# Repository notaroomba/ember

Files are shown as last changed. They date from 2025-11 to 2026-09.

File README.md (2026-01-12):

<h1 align="center">
  <br>
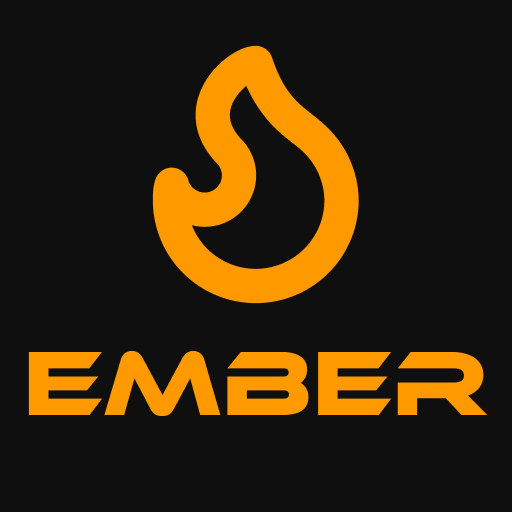
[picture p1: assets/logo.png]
  
  <br>
  Ember
  <br>
</h1>

<h4 align="center">
A high-performance USB-C powered reflow hotplate with Bluetooth connectivity and intelligent temperature control!
</h4>

<div align="center">





</div>

<p align="center">
  <a href="#key-features">Key Features</a> •
  <a href="#pcb">PCB</a> •
  <a href="#case">Case</a> •
  <a href="#heatbed">Heatbed</a> •
  <a href="#credits">Credits</a> •
  <a href="#license">License</a>
</p>

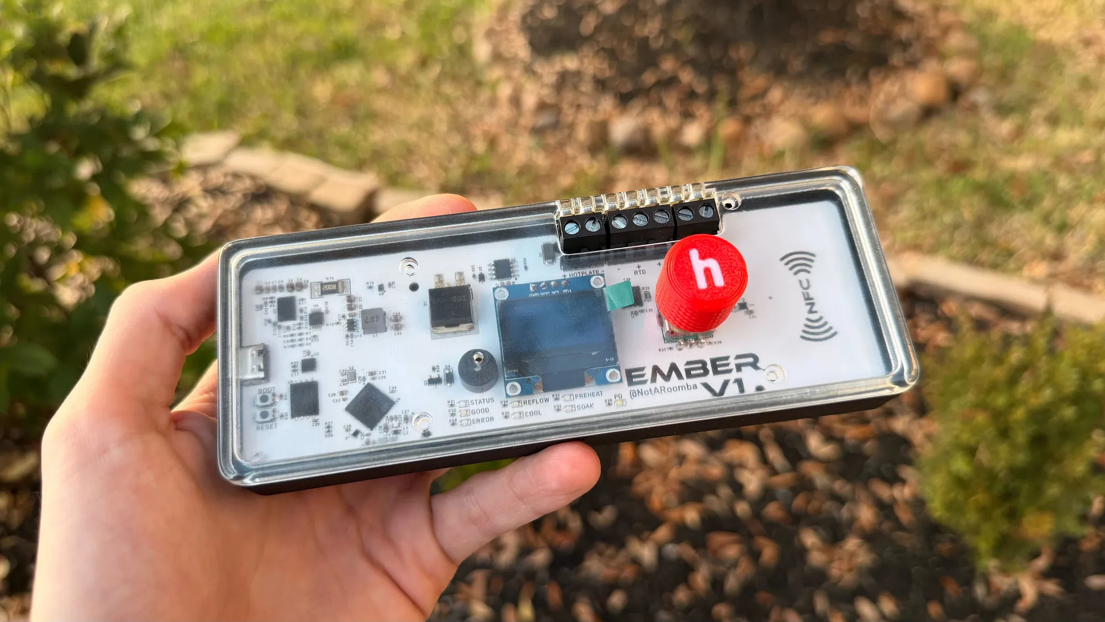
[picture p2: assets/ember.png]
Ember


<!-- <img src="blender/render.png" alt="Ember Render" width="800"/> -->

## Key Features

- **USB-C Power Delivery** up to 100W (20V) using TI's TPS25730D
- **STM32WB55CG** microcontroller with Bluetooth support
- **Large ~~400mm x 400mm~~ ~~200mm x 200mm~~ 120mm x 120mm (for now) flexible heatbed** for big PCB reflow
- **Dual temperature sensing** with MAX6675 thermocouple and PT1000 RTD
- **OLED display** with rotary encoder for easy control and preset management
- **NFC support** for wireless temperature profile transfer and preset storage
- **Gate driver** for precise PWM heatbed control
- **Current and board temperature monitoring** for safety
- **32MB Flash memory** for graphics and data storage
- **Portable design** with custom acrylic / nylon case

## PCB

Designed in KiCad!

### Schematic

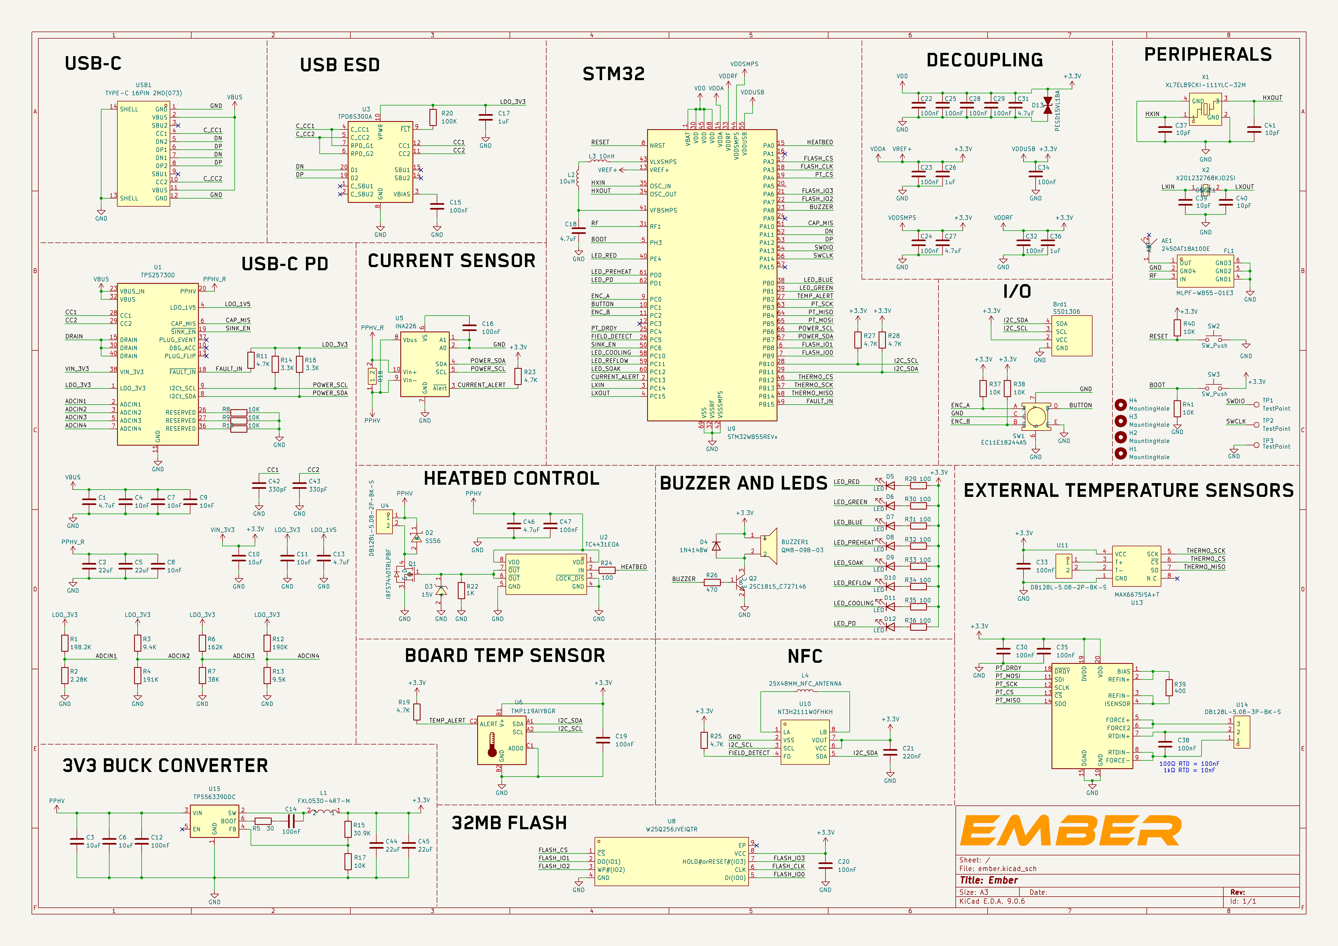
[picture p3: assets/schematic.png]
Schematic


### PCB Layout

**Front:**
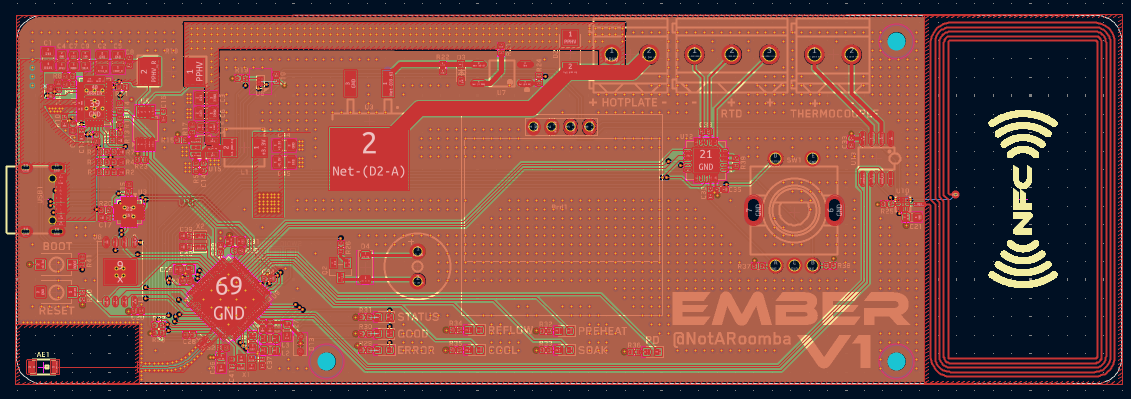
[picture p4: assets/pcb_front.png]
PCB Front


**Back:**
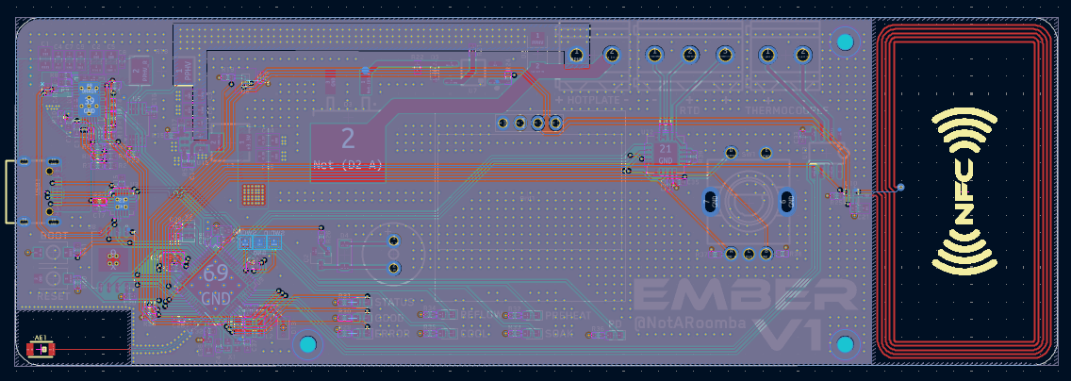
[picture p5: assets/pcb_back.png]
PCB Back


**Ground Plane:**
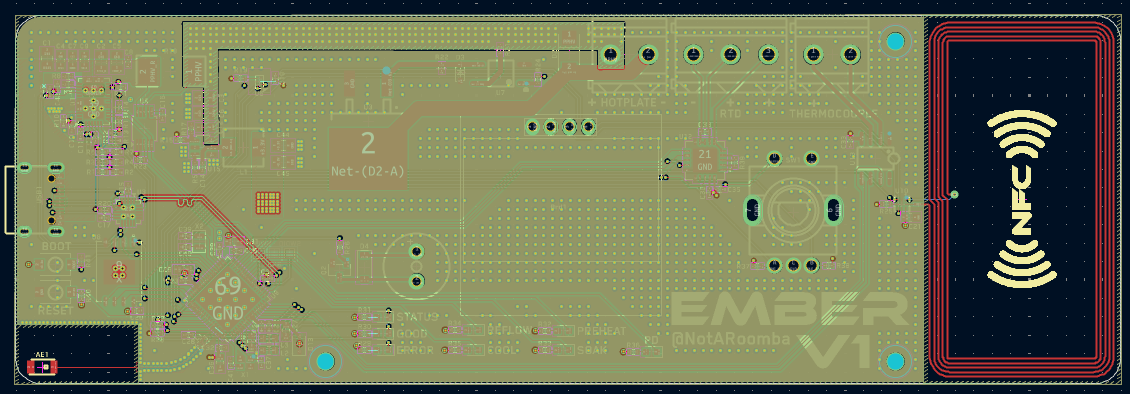
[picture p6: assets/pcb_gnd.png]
PCB Ground


**Power Plane:**
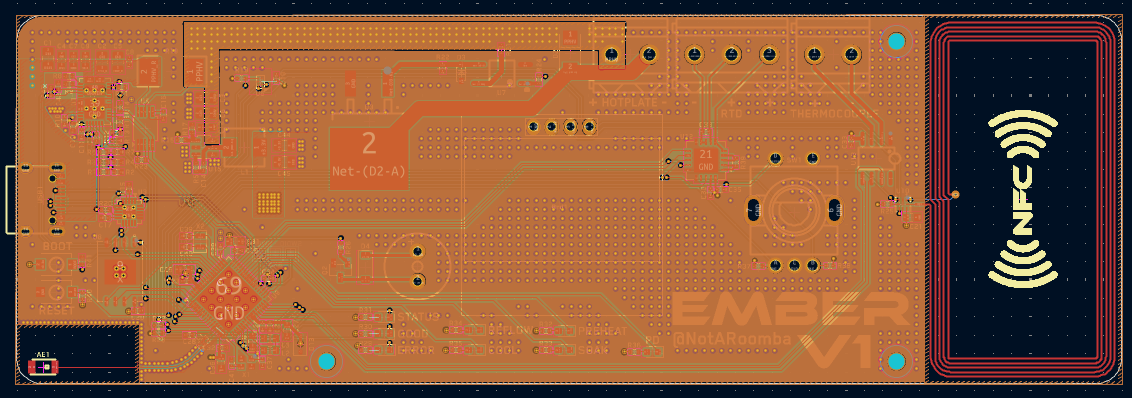
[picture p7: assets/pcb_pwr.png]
PCB Power


Board dimensions: 50mm x 150mm

## Case

Custom designed case in OnShape with practical features:

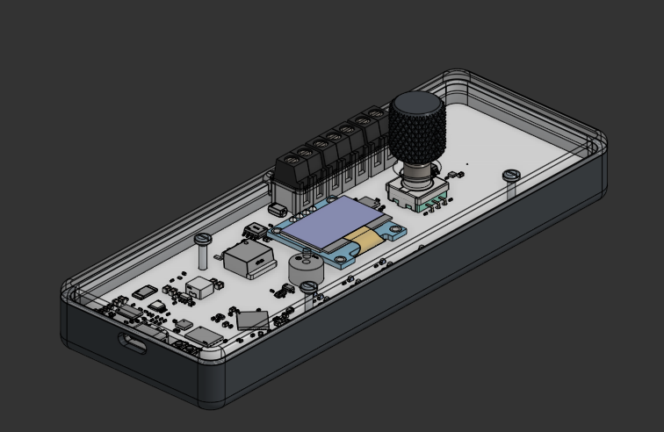
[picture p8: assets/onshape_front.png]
Case Front View

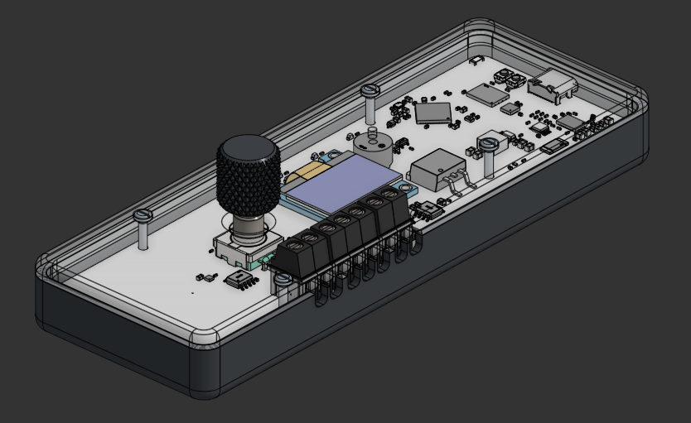
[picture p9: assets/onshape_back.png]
Case Back View


Features:
- **USB-C port cutout** with flush cable routing
- **Screw terminal access** for heatbed and temperature sensor connections
- **Heatset inserts** for secure assembly with slotted cylindrical head screws
- **High-quality materials**: PA11-HP Nylon base with acrylic top for visibility
- **Rounded corners** for aesthetics and safety

## Heatbed

The heatbed uses JLCPCB's flexible heater technology for cost-effective large-area heating.

The flexible heater connects to the main PCB via screw terminals!

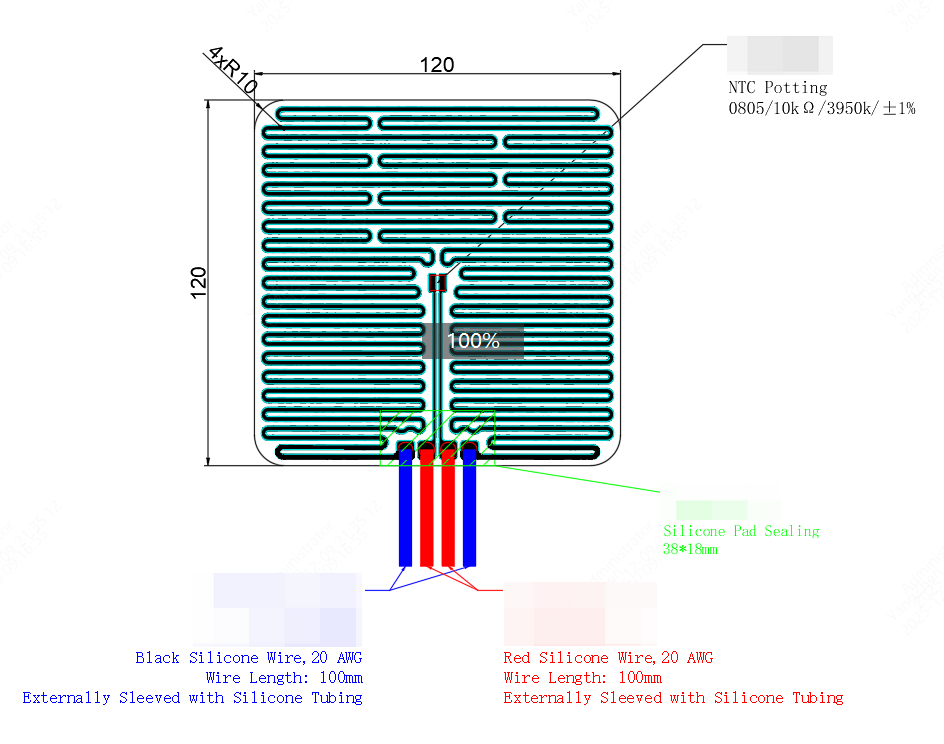
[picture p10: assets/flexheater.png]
Heatbed


## 3D Renders

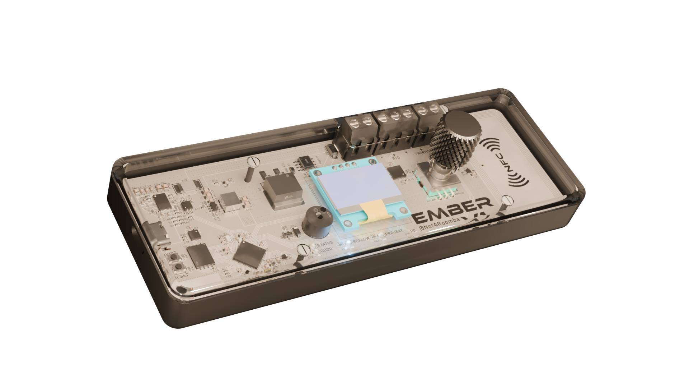
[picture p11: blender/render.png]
Render 1

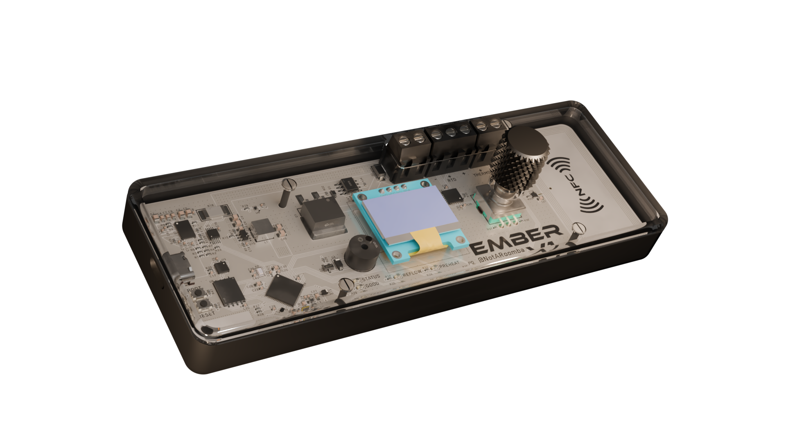
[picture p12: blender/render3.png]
Render 2

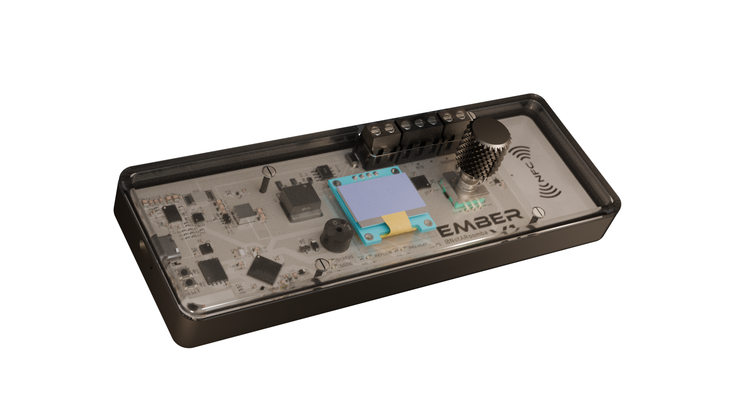
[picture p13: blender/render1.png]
Render 1

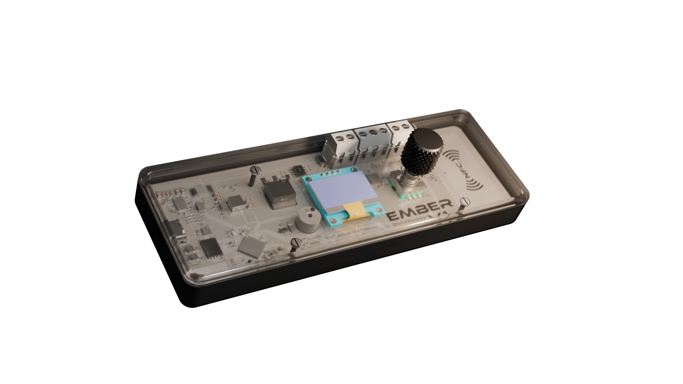
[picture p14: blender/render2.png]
Render 2


## Credits

This project uses:

- [KiCad](https://www.kicad.org/)
- [OnShape](https://www.onshape.com/) for case design
- [Blender](https://www.blender.org/) for 3D renders
- [STM32CubeMX](https://www.st.com/en/development-tools/stm32cubemx.html)
- Inspiration from [this reflow hotplate project](https://github.com/ikajdan/reflow-hot-plate)
- [Arduino GFX Tool](https://arduinogfxtool.netlify.app/) for OLED UI/UX design

## You may also like...

- [Cyberboard](https://github.com/NotARoomba/Cyberboard) – A Raspberry Pi Pico-sized STM32 development board with Bluetooth
- [Trace](https://github.com/NotARoomba/Trace) – A comprehensive PCB ruler with reference footprints
- [CyberCard](https://github.com/NotARoomba/CyberCard) – A Cyberpunk themed NFC hacker card
- [Niveles De Niveles](https://github.com/NotARoomba/NivelesDeNiveles) – Real-time flood alert app
- [Linea](https://github.com/NotARoomba/Linea) – An EMR tablet
- [Tamaki](https://github.com/NotARoomba/Tamaki) – A cute HackPad

## License

MIT

---

> [notaroomba.dev](https://notaroomba.dev) &nbsp;&middot;&nbsp;
> GitHub [@NotARoomba](https://github.com/NotARoomba) &nbsp;&middot;&nbsp;

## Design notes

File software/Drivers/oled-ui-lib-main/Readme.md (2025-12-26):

# Arduino Oled UI Components 
A component-based UI library for SSD1306 oled screens, tested on 128x64 version.

## Prerequisites
- **Adafruit SSD1306 Library**: Install via Arduino Library Manager.

## Usage
Include relevant headrs in your sketch.
```cpp
#include <Adafruit_GFX.h>
#include <Adafruit_SSD1306.h>

#include "UIRenderer.h"
#include "UILabel.h"
#include "UIButton.h"
// Include other components as needed
```

### Basic Example
This example displayes a label and a button. See examples/ folder for further usage examples.
```cpp
#include <SPI.h>
#include <Wire.h>
#include <Adafruit_GFX.h>
#include <Adafruit_SSD1306.h>

#include "UIRenderer.h"
#include "UILabel.h"
#include "UIButton.h"

#define SCREEN_WIDTH 128
#define SCREEN_HEIGHT 64
#define OLED_RESET    -1

Adafruit_SSD1306 display(SCREEN_WIDTH, SCREEN_HEIGHT, &Wire, OLED_RESET);

// Instantiate the UI renderer
UIRenderer ui(display);

// Global variables
UILabel* helloLabel;
UIButton* clickButton;

void onButtonClick() {
  Serial.println("Button clicked!");
}

void setup() {
  Serial.begin(115200);

  if (!display.begin(SSD1306_SWITCHCAPVCC, 0x3C)) {
    Serial.println(F("SSD1306 allocation failed"));
    for (;;);
  }

  // Create UI components
  helloLabel = new UILabel("Hello, World!", 0, 0, 2);
  clickButton = new UIButton("Click Me", 0, 30, 80, 16, WHITE, BLACK, onButtonClick);

  // Add components to UI renderer
  ui.addComponent(helloLabel);
  ui.addComponent(clickButton);

  // Initial render
  ui.render();
}

void loop() {
  // Simulate button press (for demonstration purposes)
  delay(2000);
  onButtonClick();
}
```

### Components Reference

#### UILabel

Displays text on the screen.

**Usage Example**:

```
UILabel* myLabel = new UILabel("Sample Text", x, y, textSize, textColor);
ui.addComponent(myLabel);
```

- **Parameters**:
  - `text`: The text to display.
  - `x`, `y`: Position on the screen.
  - `textSize`: Size of the text (default is `1`).
  - `textColor`: Color of the text (default is `WHITE`).

#### UIButton

A clickable button with a label.

**Usage Example**:

```
void onButtonClick() {
  // Handle button click
}

UIButton* myButton = new UIButton("Press", x, y, width, height, bgColor, textColor, onButtonClick);
ui.addComponent(myButton);
```

- **Parameters**:
  - `label`: Button label text.
  - `x`, `y`: Position on the screen.
  - `width`, `height`: Size of the button.
  - `bgColor`: Background color (default is `WHITE`).
  - `textColor`: Text color (default is `BLACK`).
  - `onClick`: Callback function when the button is clicked.

#### UISeparator

Draws a horizontal line to separate UI sections.

**Usage Example**:

```
UISeparator* separator = new UISeparator(x, y, width, color);
ui.addComponent(separator);
```

- **Parameters**:
  - `x`, `y`: Starting position.
  - `width`: Length of the separator.
  - `color`: Line color (default is `WHITE`).

#### UISpinner

An animated spinner to indicate processing.

**Usage Example**:

```
UISpinner* spinner = new UISpinner(centerX, centerY, radius, color);
ui.addComponent(spinner);
```

- **Parameters**:
  - `centerX`, `centerY`: Center position.
  - `radius`: Size of the spinner.
  - `color`: Spinner color (default is `WHITE`).

**Note**: Call `spinner->update()` in the loop to animate.

#### UINavbar

A navigation bar with menu items.

**Usage Example**:

```
void onHomeSelected() {
  // Handle home selection
}

UINavbar* navbar = new UINavbar(x, y, width, height);
navbar->addItem(new UINavbarItem("Home", onHomeSelected));
ui.addComponent(navbar);
```

- **Parameters**:
  - `x`, `y`: Position on the screen.
  - `width`, `height`: Size of the navbar.
  - `bgColor`, `textColor`, `selectedColor`: Colors for various states.

#### UIProgressBar

Displays progress for operations.

**Usage Example**:

```
UIProgressBar* progressBar = new UIProgressBar(x, y, width, height);
progressBar->setProgress(50); // Set progress to 50%
ui.addComponent(progressBar);
```

- **Parameters**:
  - `x`, `y`: Position on the screen.
  - `width`, `height`: Size of the progress bar.
  - `bgColor`, `barColor`: Colors for background and progress.

#### UIRadioButton

Allows selection from multiple options.

**Usage Example**:

```
void onRadioSelection(uint8_t index) {
  // Handle selection
}

UIRadioButton* radioGroup = new UIRadioButton(x, y, textSize, textColor, onRadioSelection);
radioGroup->addOption(new UIRadioOption("Option 1"));
radioGroup->addOption(new UIRadioOption("Option 2"));
ui.addComponent(radioGroup);
```

- **Parameters**:
  - `x`, `y`: Position on the screen.
  - `textSize`: Text size (default is `1`).
  - `textColor`: Text color (default is `WHITE`).
  - `onSelectionChange`: Callback function when the selection changes.

#### UIToggleSwitch

A binary on/off switch.

**Usage Example**:

```
void onToggle(bool state) {
  // Handle toggle
}

UIToggleSwitch* toggleSwitch = new UIToggleSwitch(x, y, width, height, initialState, onColor, offColor, onToggle);
ui.addComponent(toggleSwitch);
```

- **Parameters**:
  - `x`, `y`: Position on the screen.
  - `width`, `height`: Size of the switch.
  - `initialState`: Starting state (`true` for on, `false` for off).
  - `onColor`, `offColor`: Colors for the on and off states.
  - `onToggle`: Callback function when the state changes.

#### UINumericInput

Adjust numerical values.

**Usage Example**:

```
void onValueChange(int32_t newValue) {
  // Handle value change
}

UINumericInput* numericInput = new UINumericInput(x, y, minValue, maxValue, initialValue, textSize, textColor, onValueChange);
ui.addComponent(numericInput);
```

- **Parameters**:
  - `x`, `y`: Position on the screen.
  - `minValue`, `maxValue`: Minimum and maximum values.
  - `initialValue`: Starting value.
  - `textSize`: Text size (default is `1`).
  - `textColor`: Text color (default is `WHITE`).
  - `onValueChange`: Callback function when the value changes.

#### UIMessageBox

Displays messages or alerts.

**Usage Example**:

```
UIMessageBox* messageBox = new UIMessageBox("Alert!", x, y, width, height);
messageBox->show(); // To display
messageBox->hide(); // To hide
ui.addComponent(messageBox);
```

- **Parameters**:
  - `message`: The message to display.
  - `x`, `y`: Position on the screen.
  - `width`, `height`: Size of the message box.
  - `bgColor`, `textColor`, `borderColor`: Colors for background, text, and border.

#### UILineChart

Visualizes data trends.

**Usage Example**:

```
UILineChart* lineChart = new UILineChart(x, y, width, height);
lineChart->addDataPoint(sensorValue);
ui.addComponent(lineChart);
```

- **Parameters**:
  - `x`, `y`: Position on the screen.
  - `width`, `height`: Size of the chart.
  - `lineColor`: Color of the line (default is `WHITE`).

#### UIDropdownMenu

Selects from a list of options.

**Usage Example**:

```
void onDropdownSelect(uint8_t index) {
  // Handle selection
}

UIDropdownMenu* dropdownMenu = new UIDropdownMenu(x, y, width, height, bgColor, textColor, selectedColor, onDropdownSelect);
dropdownMenu->addItem("Option A");
dropdownMenu->addItem("Option B");
ui.addComponent(dropdownMenu);
```

- **Parameters**:
  - `x`, `y`: Position on the screen.
  - `width`, `height`: Size of the dropdown menu.
  - `bgColor`, `textColor`, `selectedColor`: Colors for background, text, and selected item.
  - `onItemSelect`: Callback function when an item is selected.

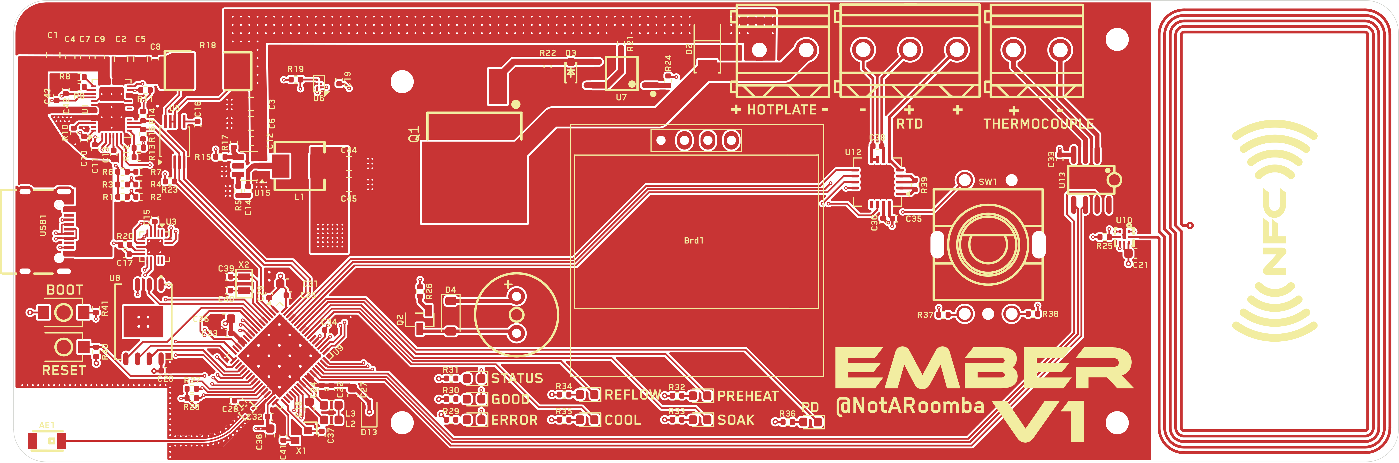
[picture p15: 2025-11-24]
assets/ember-F_Cu.png

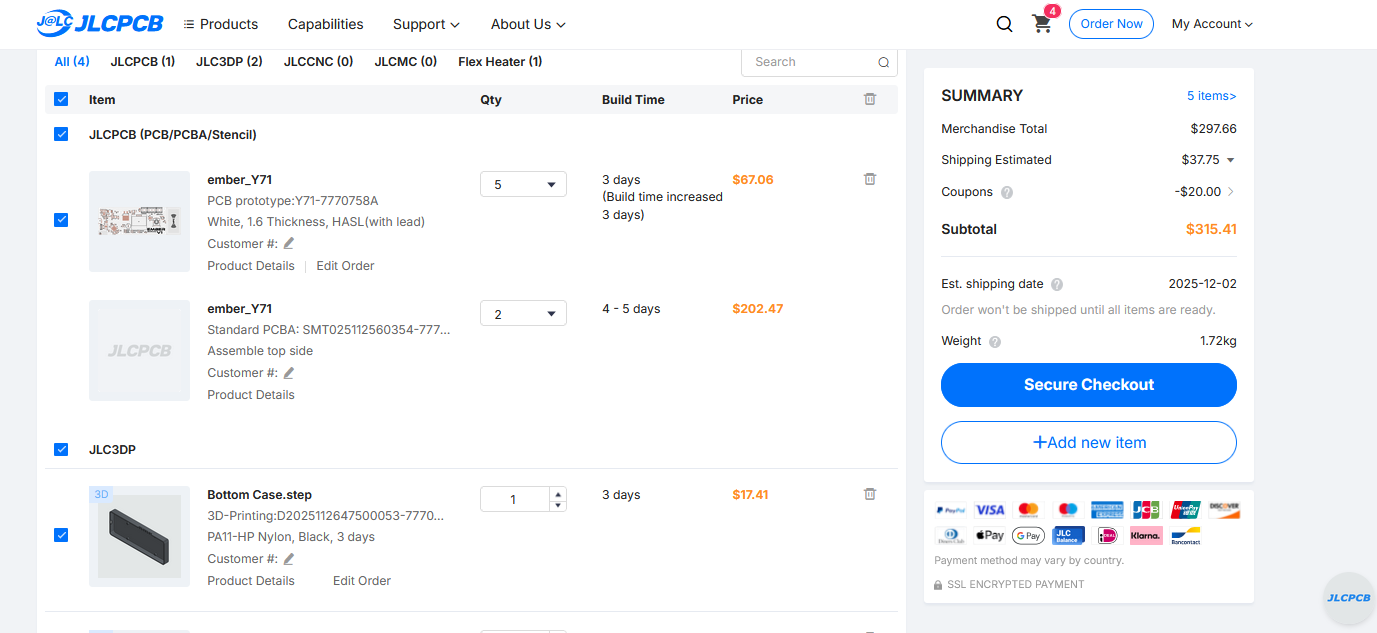
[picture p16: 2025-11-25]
assets/jlc_1.png

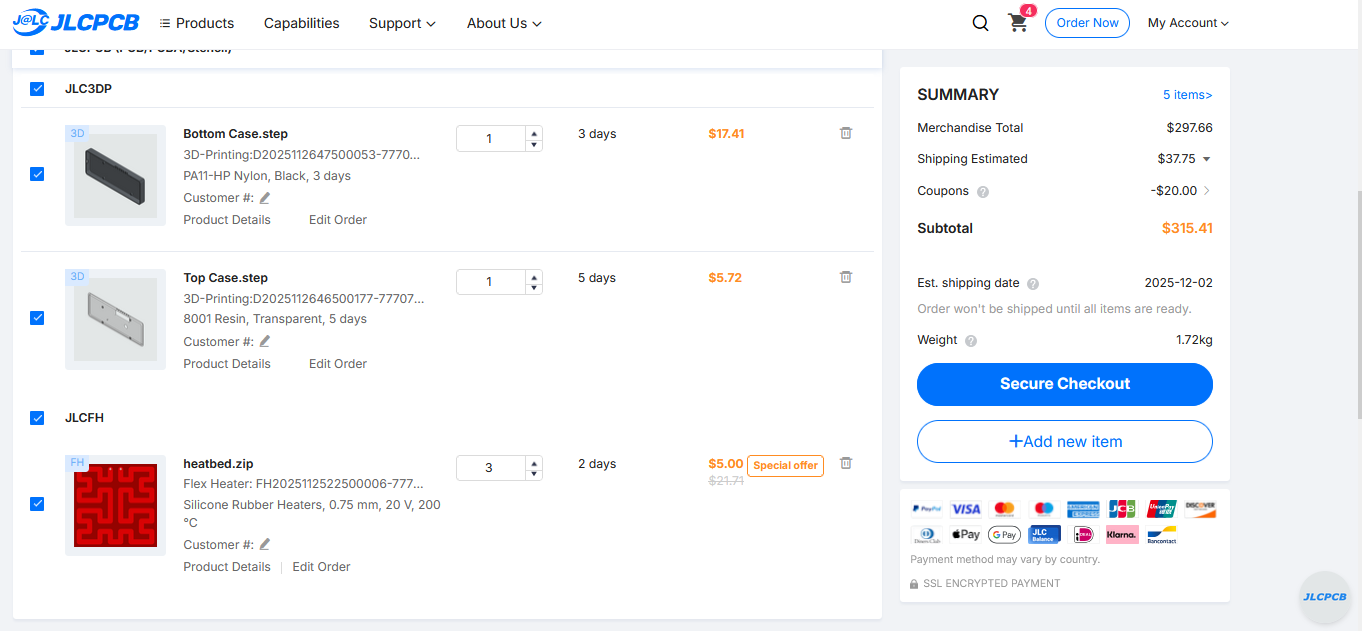
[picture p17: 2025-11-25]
assets/jlc_2.png

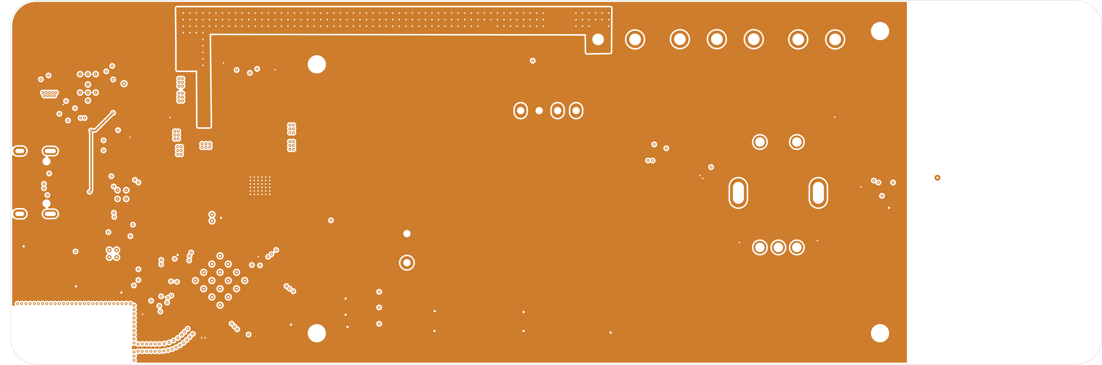
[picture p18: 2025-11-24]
assets/ember-In2_Cu.png

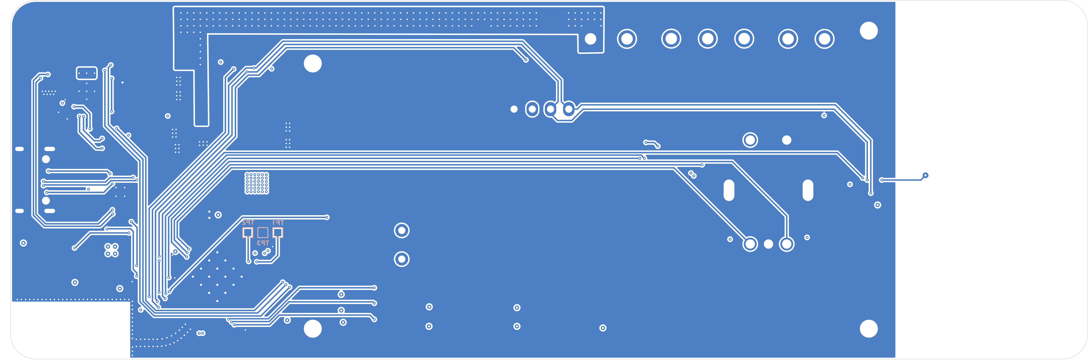
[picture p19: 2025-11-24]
assets/ember-B_Cu.png

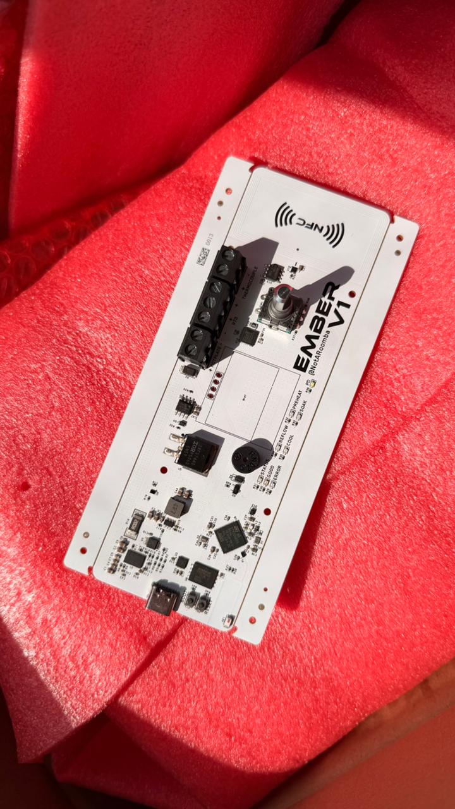
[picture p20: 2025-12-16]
assets/ember_pcb.jpeg

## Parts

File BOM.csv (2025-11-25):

Item | Price | Source | Alt Source
PT1000 | 4.28 | https://es.aliexpress.com/item/1005010267999683.html
Thermocouple | 2.66 | https://es.aliexpress.com/item/4000097994613.html
OLED | 2.24 | https://es.aliexpress.com/item/1005006152880748.html
Heatset Inserts | 3.70 | https://es.aliexpress.com/item/1005006838108683.html
Potentiometer Knob | 1.25 | https://es.aliexpress.com/item/1005009085015664.html
EC11 | 3.30 | https://es.aliexpress.com/item/1005007703545657.html
Black Nylon M2 Screws | 0.88 | https://es.aliexpress.com/item/1005004359782700.html
PCB | 269.53 | JLCPCB
Top Case (Clear) | 5.72 | JLC3DP
Bottom Case (High temp filament) | 17.41 | JLC3DP
Heatbed | 5.00 | JLCFH
Shipping (JLC) (DDP) | 37.75 | JLC
Shipping (AliExpress) | 8.11 | AliExpress
JLC Coupon | -20.00 | JLC
Total | 341.83

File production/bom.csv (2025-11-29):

Designator | Footprint | Quantity | Value | LCSC Part #
AE1 | ANT-SMD_L3.2-W1.6 | 1 | 2450AT18A100E | C89334
BRD1 | 128x64OLED | 1 | SSD1306
BUZZER1 | BUZ-TH_BD9.0-P4.00-D0.6-FD | 1 | QMB-09B-03 | C96256
C1 | 0805 | 1 | 4.7uF
C10, C11 | 0402 | 2 | 10uF
C12, C47 | 0603 | 2 | 100nF
C13 | 0402 | 1 | 4.7uF
C14, C15, C16, C19, C20, C22, C23, C24, C25, C28, C29, C30, C32, C33, C34, C35, C38 | 0402 | 17 | 100nF
C17 | 0402 | 1 | 1uF
C18, C27, C31, C46 | 0603 | 4 | 4.7uF
C2, C44, C45, C5 | 0805 | 4 | 22uF
C21 | 0603 | 1 | 220nF | C21120
C26, C36 | 0603 | 2 | 1uF
C3, C6 | 0805 | 2 | 10uF
C37, C39, C40, C41 | 0402 | 4 | 10pF
C4, C7, C9 | 0603 | 3 | 10nF
C42, C43 | 0402 | 2 | 330pF
C8 | 0402 | 1 | 10nF
D10, D11, D8, D9 | 0603 | 4 | LED | C965800
D12 | 0603 | 1 | LED | C2290
D13 | D_SOD-323 | 1 | PESD15VL1BA
D2 | SMA_L4.3-W2.6-LS5.2-RD | 1 | SS56 | C65009
D3 | SOD-323_L1.7-W1.3-LS2.6-RD | 1 | 15V | C19077448
D4 | D_SOD-123 | 1 | 1N4148W
D5 | 0603 | 1 | LED | C965799
D6 | 0603 | 1 | LED | C19171301
D7 | 0603 | 1 | LED | C965807
FL1 | FILTER-SMD_6P-L1.6-W1.0-P0.50-BL | 1 | MLPF-WB55-01E3 | C2651048
L1 | IND-SMD_L5.4-W5.2_FXL0530 | 1 | FXL0530-4R7-M | C177246
L2 | 0603 | 1 | 10uH
L3 | 0603 | 1 | 10nH
L4 | 25X48MM_NFC_ANTENNA | 1 | 25X48MM_NFC_ANTENNA
Q1 | TO-263-2_L10.0-W9.1-P5.08-LS15.2-BR | 1 | IRFS7440TRLPBF | C409762
Q2 | SOT-23-3_L2.9-W1.3-P1.90-LS2.4-BR | 1 | 2SC1815_C727146 | C727146
R1 | 0402 | 1 | 198.2K | C3013157
R10, R17, R37, R38, R40, R41, R8, R9 | 0402 | 8 | 10K
R11, R19, R23, R25, R27, R28 | 0402 | 6 | 4.7K
R12 | 0402 | 1 | 190K | C2998070
R13 | 0402 | 1 | 9.5K | C96273
R14, R16 | 0402 | 2 | 3.3K
R15 | 0402 | 1 | 30.9K
R18 | RES-SMD_L6.4-W3.2-1 | 1 | HOLLR2512-3W-2MR-1% | C2994640
R2 | 0402 | 1 | 2.28K | C2998174
R20 | 0402 | 1 | 100K
R22 | 0402 | 1 | 1K
R24, R29, R30, R31, R32, R33, R34, R35, R36 | 0402 | 9 | 100
R26 | 0402 | 1 | 470
R3 | 0402 | 1 | 9.4K | C852970
R39 | 0805 | 1 | 400 | C153298
R4 | 0402 | 1 | 191K | C2998070
R5 | 0402 | 1 | 30
R6 | 0402 | 1 | 162K
R7 | 0402 | 1 | 38K | C852750
SW1 | SW-TH_EC11E18244A5 | 1 | EC11E18244A5 | C255515
SW2, SW3 | SW-SMD_L3.9-W3.0-P4.45 | 2 | SW_Push | C720477
TP1, TP2, TP3 | TestPoint_Pad_1.0x1.0mm | 3 | TestPoint
U1 | Texas_REF0038A_WQFN-38-2EP_6x4mm_P0.4 | 1 | TPS25730D
U10 | XQFN-8_L1.6-W1.6-P0.50-BL_NT3H2111W0FHKH | 1 | NT3H2111W0FHKH | C710403
U11, U4 | CONN-TH_2P-P5.08_DB128L-5.08-2P-BK-S | 2 | DB128L-5.08-2P-BK-S | C430601
U12 | TQFN-20-1EP_5x5mm_P0.65mm_EP3.25x3.25mm | 1 | MAX31865xTP
U13 | SOIC-8_L5.0-W4.0-P1.27-LS6.0-BL | 1 | MAX6675ISA+T | C16030
U14 | CONN-TH_3P-P5.08_DB128L-5.08-3P-BK-S | 1 | DB128L-5.08-3P-BK-S | C430602
U15 | SOT-23-6 | 1 | TPS56339DDC
U2 | SOIC-8_L4.9-W3.9-P1.27-LS6.0-BL | 1 | TC4431EOA | C2909520
U3 | WQFN-20-1EP_3x3mm_P0.4mm_EP1.7x1.7mm_ThermalVias | 1 | TPD6S300A
U5 | VSSOP-10_3x3mm_P0.5mm | 1 | INA226
U6 | Texas_DSBGA-6_0.95x1.488mm_Layout2x3_P0.4mm | 1 | TMP119AIYBGR
U8 | WSON-8_L8.0-W6.10-P1.27-BL-EP | 1 | W25Q256JVEIQTR | C97522
U9 | QFN-68-1EP_8x8mm_P0.4mm_EP6.4x6.4mm | 1 | STM32WB55REVx
USB1 | USB-C-SMD_TYPE-C-6PIN-2MD-073 | 1 | TYPE-C 16PIN 2MD(073) | C2765186
X1 | CRYSTAL-SMD_4P-L2.0-W1.6-BL | 1 | XL7EL89CKI-111YLC-32M | C2965582
X2 | OSC-SMD_L2.0-W1.2 | 1 | X201232768KJD2SI | C383843

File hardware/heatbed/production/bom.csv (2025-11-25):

Designator | Footprint | Quantity | Value | LCSC Part #
R1, R2 | 0805 | 2 | R

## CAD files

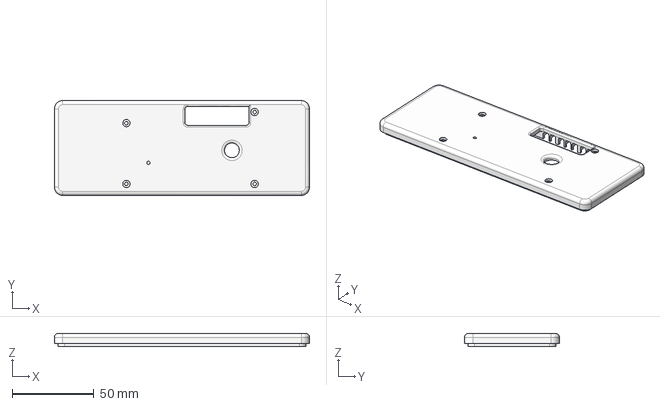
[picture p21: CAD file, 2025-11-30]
hardware/case/Top Case.step
156.0 x 58.0 x 8.00 mm

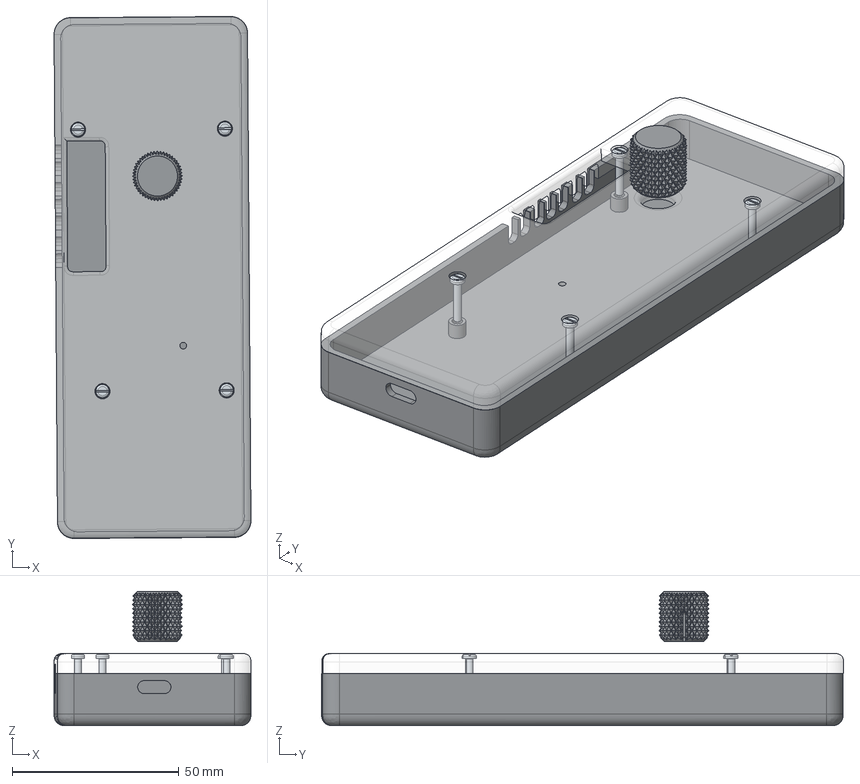
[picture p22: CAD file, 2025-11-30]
hardware/case/Ember_NO_PCB.step
59.0 x 156.4 x 40.3 mm
Slotted pan head screw M2x0.40 x 12 x 4
EC11 Knob
Bottom Case
Top Case

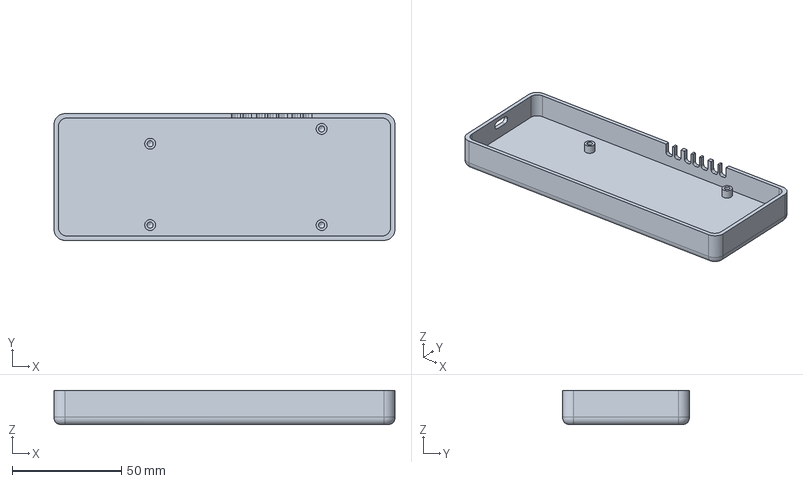
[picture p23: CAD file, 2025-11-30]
production/Bottom Case.step
156.0 x 58.0 x 15.6 mm

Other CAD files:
hardware/board/ember/ember/ember.ipt

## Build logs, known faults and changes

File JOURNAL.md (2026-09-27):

<!--
  Exported from Hack Club Blueprint on 2026-09-27.
  Source: https://blueprint.hackclub.com/projects/1701
-->

## 11/14/2025 - Research  

_Time spent: 3.0h_  

This is another project that surged out of nowhere (like trace) but mainly because I want to be able to solder/reflow my own PCB's in my house to be able to save cost and make bigger and better projects in the future (\*cough\* \*cough\* robotic arm \*cough\* \*cough\*). 

While I could buy a hotplate in the shop, I feel like it's too small and I might need to reflow bigger PCB's so just in case, I want to build a large custom hotplate that has these characteristics:

- Powered by USB-C
- Portable/Easy to store
- OLED screen + knob and button to config
- Cool looking case (opportunity to learn CAD before making a robotic arm/rocket)

Looking through the internet to see if anyone has done anything like this, I stumbled on this [repo](https://github.com/ikajdan/reflow-hot-plate/tree/main). While cool looking, it uses an external power supply and has a relatively small heatbed (80mm x 80mm). I'm aiming for 4 times that (in terms of area) with a 160mm x 160mm heatbed (or even bigger).

Doing more research and looking at materials, making a heatbed out of aluminum and one layer of copper costs a lot for big boards (slabs of aluminum)



Or even a bit smaller:



BUT, JLCPCB HAS THIS NEW COOL THING CALLED FLEX HEATERS THAT ARE WAYY CHEAPER AND CAN GO FOR BIGGER BC THEY'RE ALL AT 9 USD! SO being the capitalist that I am, I am going to capitalize on these savings and use one.



Now all that's left is to design the board. As I want USB-C PD, I am thinking about using a STM32G0B1KE (32 pin version) as it's powerful enough to do everything that I want it to do. I also would need a 3V3 converter (LM3281YFQR). In addition to a mosfet to control the how much current is going through (PWM). I also plan on adding a bunch of redundancy like USB-C ESD protection, fuses, current sensors, and temperature sensors (Thermocouple and Pt1000). 

Since this is going to be a flexible heater, I will also need a way to "prop" it up in the air so that it doesn't burn my desk. I plan on using an aluminum sheet with a hole in each corner to insert a "leg" (screw or smth) to be able to prop it up. Then at the bottom I plan on having a nice case (titanium /j) for the PCB and screw terminals to connect it to the hotplate/heatpad/flex heater.  

## 11/15/2025 - Start of Schematic  

_Time spent: 7.0h_  

I first created a new KiCad project and then opened up STM32CubeMX and followed this [guide](https://wiki.st.com/stm32mcu/wiki/STM32StepByStep:Getting_started_with_USB-Power_Delivery_Sink) on the ST website to configure USB PD. I also changed the processor to the STM32G0B1CBT6 as the other one didn't have a second CC pin due to the pin count.

Yknow what, scratch that, I'm a Texan and should be loyal to TI. So I'm gonna go with a TPS25730D and then use an STM32WB55 to get bluetooth support (everythings better with bluetooth lol). Jokes aside, I am going with TI because I want to complete this project in 3 days (crazy right?) and I feel more comfortable with their chips (Also serves as practice for when I have to work with Athena's PD chip).

For the mosfet I will be using IRFB3207 and TLP183 to drive it (taken from the original repo) and for temperature sensors, MAX6675 (thermocouple to digital), and a PT1000 with opamps to filter/amplify the signal. 

I will also be using LM22676MR-ADJ as a good step down converter from high voltages (42V just in case I want more power lol).



I added the components and started wiring up the ESD and USB-C port first:



After that I finished wiring up the USB-C PD chip. (Yes I made sure that there were pull up resistors on the I2C lines)



## 11/16/2025 - Worked on Schematic  

_Time spent: 8.0h_  

I started wiring up the STM32 and configuring it in STM32CubeMX. THIS TIME LOOKING AT THE REFERENCE SCHEMATIC AND NOT COPY PASTING TO AVOID [ERRORS](https://blueprint.hackclub.com/projects/491).





THIS TIME I ACTUALLY ADDED PULL UP RESISTORS ON THE I2C LINES AND DOUBLE CHECKED THE DECOUPLING CAPACITOR VALUES. 

I researched a bit about the different screens like the ones on the flipper zero but the standard I2C OLED is fine (SSD1306). I found this cool tool to create UI/UX so I'll put it here to save for later (https://arduinogfxtool.netlify.app/)

I also added in a bit more stuff like current sensor, buzzer, and board thermometer just in case. I might also add in NFC functionality to be able to wirelessly transfer temp data to the board/have presets set in NFC tags and I just put it on top and let it go (overkill but why half ass it).

I also added a 32MB flash to add images/graphcs onto the OLED (might be possible)

I hope to find this encoder somewhere: https://tech.alpsalpine.com/e/products/detail/EC11E18244A5/
 I also spent some time thinking about the case:


(very crude)

I'd want it made out of a high quality plastic (PA11-HP Nylon) or acrylic to be able to see the board interior with rounded corners and space to fit the board and OLED/Encoder. I might also include one of those push-push-switches to turn it on or off. (sends signal to STM32 to disable USB-C PD and turns off the display/lights. OR I COULD DO THE BACK AS (PA11-HP Nylon) AND THE TOP COVER AS ACRYLIC, but I'm too tired to think so tmrw I'll finish the schematic and start the routing.

## 11/17/2025 1 AM - STM32 Pinout and Most Peripherals  

_Time spent: 5.0h_  

I started by first defining the pinout for the STM32, as I wanted to use most of the pins, I added some status LED's and a buzzer. Continuing on from yesterday's work, I skimmed through the datasheets of each component to see which extra pins I would need to add them immediately and not have to worry about adding them later. I had some trouble with the timers and flash as I could only use 2 timers (out of 4) so I needed a way to get input from the rotary encoder, set the heatbed, and also to control the buzzer. After researching a bit more, I ended up using LPTIM1 for the rotary encoder as I say that It had input for that.

After configuring all of the pins, my STM32 looked like this:





After that I went to work wiring up the rest of the peripherals like the flash, buzzer, board temperature sensor, current sensor, and NFC antenna.











After that, I routed the buck converter to convert from PPHV to 3.3V:



I looked carefully in the datasheet and made sure that I was using the right inductor and capacitors (looked them upon LCSC and added the part numbers). 

I also bom optimized a bit by using as many 4.7K pull-up resistors as I could to not have extra costs for different resistor values.

All that's left is to route up the external temperature sensors and also add in the connections to the heatplate. ALSO THE ROTARY ENCODER AND OLED DISPLAY. I plan on using screw terminals and making holes in the acrylic top case to be able to screw/unscrew them. I also plan on 

## 11/17/2025 1 PM - Finished Schematic and Footprints  

_Time spent: 5.0h_  

I routed up the external temperature sensors, using chips from MAXIM and ended up with this:







I then routed up the PWM hotplate channel (design taken from [here](https://github.com/ikajdan/reflow-hot-plate/tree/main)) and ended up with this:



I then proceeded to add all of the LEDs and try to find in the OLED and rotary encoder footprints and add them in:





Then I organized the board and ran an ERC to make sure that I didn't have any unconnected items. After that I found a cool font that I am going to use for all of the logos and icons and design and added it in.



Then I updated the footprints for all of the components (making sure not to use 0201) and then imported it into the schematic.



## 11/18/2025 - Start PCB Layout  

_Time spent: 6.0h_  

After finishing the schematic and selecting the footprints, I went over to the PCB and started grouping the components (ICs) together along with their passives.


(STM32 for example)

and continued until I had the rest of the components laid out. After that, I made a board outline of 50mmx150mm and then started placing the components there. From what I had in mind, I wanted the NFC tag on the opposite side of the USB-C connector and I also wanted the USB-C PPHV line to go through the top away from the other components. I wanted the Bluetooth antenna in a corner away from any noisy components so I decided to place it in the corner opposite of the PPHV line. The screw terminals I wanted in the top and preferably in the center, as well as the OLED and rotary encoder. After playing around with the layout I got something like this:



I started routing a bit but needed to work on Accelerate so I'm gonna take a break lol.  

## 11/19/2025 - PCB Routing  

_Time spent: 5.0h_  

After coming back, I had a thought. There will probably be space under the OLED so I can add in components under it. Although there will be resistors and stuff under it, I can always put a sheet of paper or smth to separate it.

0J4234.1200

1657fac49c2cba1010eac9aaf2038c93abfc49b5_2_557x500

I decided to reorganize the board to edit the space between the components:



After a while of procrastination and burnout, I finally started something:



I still have a bit of routing to go and then I'll send it for review in the KiCad Discord (first time lol) and also the blueprint channel before rendering it :sob:  

## 11/20/2025 - Design Schematic  

_Time spent: 8.0h_  

After working for a bit, I finally finished routing up most of the PCB:



I still have to impedance match the antenna and add in the 3D models and fix the silkscreen but for the most part it's done.

After that I fixed up the silkscreen aligning everything perfectly (ocd)


I entered the lock in call and finished impedance matching, edited the silkscreen, and added a few more aesthetic touches.





## 11/21/2025 - Change Buck and Heatbed  

_Time spent: 7.0h_  

After posting it in the KiCad Discord I got the feedback to use another buck converter (TPS56339DDC) as electrolytic caps don't like heat so I rewired the buck converter and then routed it up on the PCB.





This gave me more space to put the MOSFET in the middle to dissipate more heat.

Moving on to the hotplate/heatbed, I found out that the design I am basing this off of has this schematic and PCB:





and I found out that these values come from KiCad's calculator:



So to design my own, I wanted to do the same. Looking through JLCPCB's Flexible Heater capabilities, I found out that the thickness of the material can be from 30um to 50um (silicone)



Looking at the voltage drop and power consumption, I only have 20V and 100W to play around with and the 3.3V buck converted needs a minimum of 5V so I have to change the length to make sure that I have at least 5V (with a bit of leeway) to be able to use as much area as I can.

I started researching about Hilbert Curves (very interesting) and also how there is a KiCad plugin to generate it:



I was playing around with it as I am trying to generate curves to fill the space in the heating element.



I then ended up woth this 400mm x 400mm board design AND THE BEST PART IS THAT IT'S ONLY 9 USD ON JLCPCB:



So after making the heatbed and the board I now am going to design a case in OnShape.

## 11/24/2025 - CAD (Canadian Dollars)  

_Time spent: 16.0h_  



After procrastinating a bit, I decided to make the case. I had in mind to have the bottom with holes for USBcC and also have a space to add in the cables for the temp sensors and heatplate. I also thought about adding in a slope for the NFC section so that it will work for phones that have a limited range.

Then I posted the board in r/PrintedCircuitBoards and also in the KiCad discord and got some feedback for the board. I then had to change out the optocoupler for a gate driver and also added another screw hole and made them more symmetrical.



After that I worked on the case and tried to make it look good:



I also found this cool image because I want the USB-C cable flush with the socket:

CGFE8

Then after that I finished the bottom case



but I didn't know how to connect the top case to it so I will research that later.

After sleeping I thought about using heatset inserts and then also the different types of screws that I can use:

Types-of-Screw-Heads

I think a sloted head would look decent as I wanted something that has a cylindrical head.





After a bit I finally finished the CAD!


## 11/25/2025 1 AM - Blender and BOM  

_Time spent: 5.0h_  

After that I decided to put it in blender and get some nice renders of the PCB and case:

banner

render

render1

render2

Then I finished up the BOM, created a logo, and cleaned up the README:





## 11/25/2025 10 AM - Blueprint Banner  

_Time spent: 0.5h_  

This is just to update the blueprint banner after waiting on it to render, I just need to write 150 characters to fill up the requirement so that I can post this.

banner

## 12/16/2025 - USB-C PD Working + Jingle Bells  

_Time spent: 5.0h_  

ember

So I finally got the PCB and it looks cool and even better was that when I plugged it in, it didn't burn up like Cyberboard V1 (wooo) so then I started trying to turn on the LEDs (first thing you always have to do) and the STM32 kept resetting and I didn't know why until later debugging (commenting out peripherals until it worked) I found out that I had mislabled an input pin as output:





After that I started configuring the USB-C PD controller to get the status of my laptop and aja after a bit of configurint I finally was able to get PDO's (power data objects) that specify what different power options the source has:



Sadly my laptop only provides 5V@1.5A so yea...



moving on, I wanna try and get the speaker running and lookign at the datasheet I found this cool graph:



but nothign telling me at which speeds it's running at so I will make my own driver that can control the PCB duty cycle

After messing around I got jingle bells playing on the board lol.

## 12/17/2025 - NFC + PWM + Board Temp Sensor + First error  

_Time spent: 10.0h_  

I started getting a driver for the NFC chip and added it in, and also struggled a bit with the I2C address as I kept overwriting it whenever I read / write to the tag.



After that I worked on getting a basic PWM driver for the hotplate and I confirmed that the MOSFET was working.

I tested it with a multimeter at 1 Hz (it was switching lol) and then moved on to the board temp sensor. That was also really simple as there were drivers on Github and at first I found one for the tps116, after reading through the datasheet and this pull request, it was the same driver for the tps119 just with a different device id:



Moving on to the current sensor, I found out that I had wired it wrong:



(VS needed to be connected to 3V3 but luckily the regulator is next to it so I can solder a small wire connecting them:



Anyways that wasn't something critical so I moved onto getting the drivers for the external temperature sensors. These functioned over SPI and on different channels to avoid different data length errors, I then got the drivers:



and got them implemented:



after that it was time for the max6675:



I finished that but I still had a problem with the NFC, it wouldn't let me read or write to it and was unreliable at times so I went to look at the code and found out that it was trying to read and get a checksum of the data while it was being read/wrote (on field detect) and this caused a blocking operation on the storage which resulted in that unreliable behavior. After changing it to wait like 200ms it finally started working and I could get changes in the NFC reliably:



All that's left is to configure the screen and set up a PID algorithm for the heatbed (will finish that once I get the heatbed), get bluetooth to workm and get the flash / lcd working.



SO I took a bit of a break bc I got accepted into MIT and added in custom support to [play music](https://hackclub.slack.com/archives/C09SWT5DCGY/p1765950160479339?thread_ts=1762829869.254119&cid=C09SWT5DCGY) so yea lol I'ma sleep now  

## 12/26/2025 - NFC Sounds + Bluetooth + Screen Working  

_Time spent: 23.0h_  

I started in the airport trying to make some misc improvements and thought of making the board beep when an NFC tag is present, It took a little while bit I made it play a little jingle.

(Check my post in #50-days for the vid)

After that I was in another airport heading to blueprint and I was looking through this [repo](https://github.com/STMicroelectronics/STM32CubeWB/blob/7c5aa7dcd2c0abe787f922bb06a6213c724d08e4/Projects/STM32WB_Copro_Wireless_Binaries/STM32WB5x/Release_Notes.html) and apparently I needed to flash the bluetooth firmware that I was going to use on the other processor otherwise it wouldn't work. After trying to flash the FUS, I bricked one of the boards because I didn't press and hold the boot button when it was editing the option bytes. But after correctly holding down the boot button, I fixed it and was able to connect to it from my phone:



So prototype happened and then I started working on the OLED screen. I had to solder it and after realizing that I had the wrong type of solder I tried fixing it and had to hold it in a certain position for the screen to work.

WhatsApp Image 2025-12-25 at 23.23.14

after that I got a circle running from this cool library:



WhatsApp Image 2025-12-25 at 23.23.14 (2)

and after a bit I got text and a basic UI although the fonts were wonky and I needed to import more:

WhatsApp Image 2025-12-25 at 23.23.14 (1)

I still have a lot to go but thankfully my heatplate and case is coming in tomorrow so yea, I'll continue working on it.

## 12/27/2025 - UI + Case + Solder  

_Time spent: 7.0h_  



So I finally got some more fonts in after making a script that converts any ttf/otf font into a bitmap font and I imported it to make this cool menu screen.



I then worked on making a status screen to show the USB-C PD voltage as I can't use serial when connected to a power outlet so yea and I successfully got 20v although it was at 4.5A:

WhatsApp Image 2025-12-27 at 14.13.54 (2)

After a while I got a notification that my case finally came in so I went to get it and found out that everything fit perfectly lol



 All that was missing were the heatset inserts and screws. This also as around the time that I couldn't take the bad screen solder so I went out and bought some leaded solder:



And then after that I finally was able to solder correctly and it looked amazing:

WhatsApp Image 2025-12-27 at 14.13.54

I then started to look for ui libraries on the internet and stumbled upon this one:



but the only problem is that I will have to port it to C :(

For the UI, here's what I'm thinking, a main menu screen that says press to start and then you will be sent to a scrolleable menu,  it will have these entries:

- Start / Stop
- Status
- Settings
- About

The start stop button will start the hotplate controller and it will send you to a menu here you have to select between holding a temperature or a reflow profile, if you hold a temp then there will be a slider between 1-200C and for the reflow profile you will have the option to select it, no mater which option you select, there will b a confirm screen.

After you confirm, you will b sent to the status screen, this is basically where you can see how the heat plate is running and the temp and current raw and everything that you could possibly need.

In the settings bar you can change the behavior of the NFC or confirm or change the brightness of the OLED, also you can have the option to turn on or off Bluetooth discovery to control the board.

In the about scan it will how the firmware version and the credits.

Now that I have that planned out I will try and connect the hotplate to see how hot it can get:

flexheater

## 2/28/2026 - Finished stuffs  

_Time spent: 29.5h_  

Okay so basically I kinda want this shipped before BP ends and after switching computers like 5 times I forgot everything I've done in that time but I made it reflow trace among other things

I also added in a cool UI that has a menu screen where you can change the temperature among other things. I don't have any pictures bc I can't find them and yea... look at my commits to see my progress! I ordered a replacement part on Digikey for the temp sensor as I was dyslexic and wanted to solder it again but the order didn't go through after ordering it twice so yea...

I demoed this at MIT Blueprint and Clay saw it working once and I almost burned a hole through HQ trying to boil water. The ui could be better and yea



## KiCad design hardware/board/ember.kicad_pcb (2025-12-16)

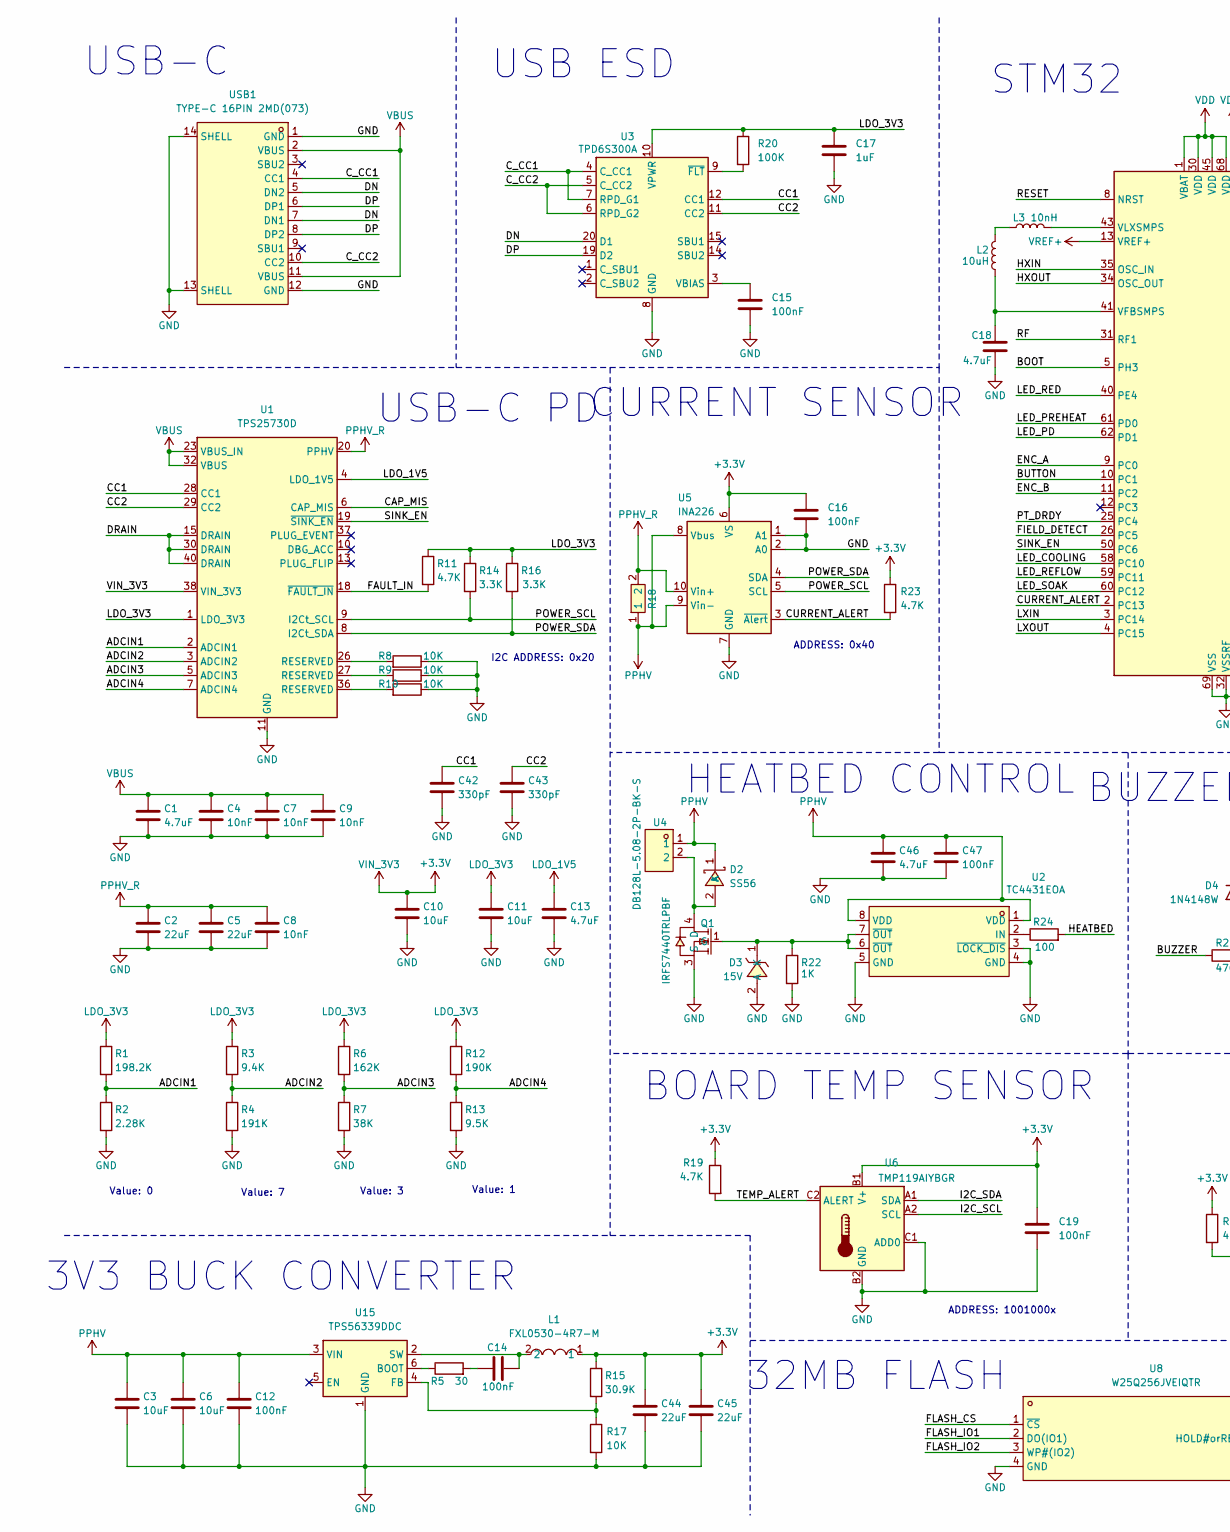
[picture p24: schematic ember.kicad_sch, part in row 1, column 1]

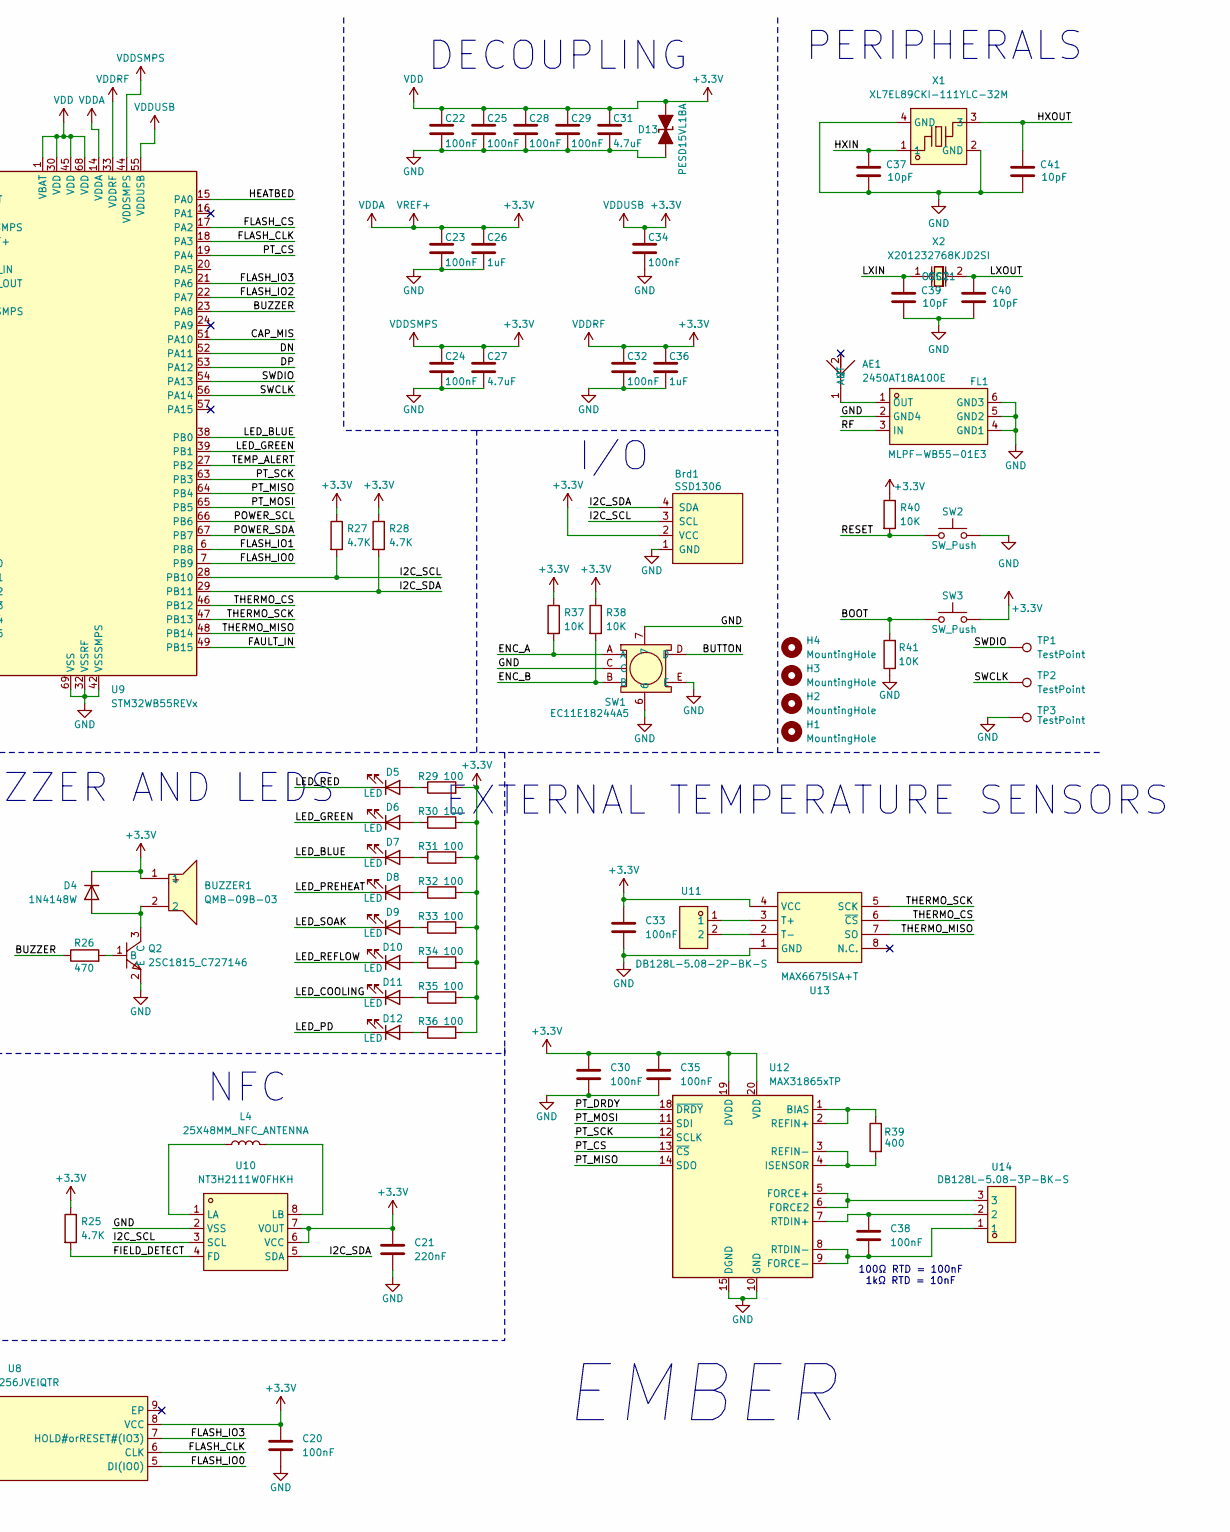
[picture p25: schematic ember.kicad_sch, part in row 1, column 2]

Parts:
AE1: 2450AT18A100E; ANT-SMD_L3.2-W1.6; LCSC Part C89334
BUZZER1: QMB-09B-03; BUZ-TH_BD9.0-P4.00-D0.6-FD; LCSC Part C96256
Brd1: SSD1306; 128x64OLED
C1: 4.7uF; C_0805_2012Metric
C2, C5, C44, C45: 22uF; C_0805_2012Metric
C3, C6: 10uF; C_0805_2012Metric
C4, C7, C9: 10nF; C_0603_1608Metric
C8: 10nF; C_0402_1005Metric
C10, C11: 10uF; C_0402_1005Metric
C12, C47: 100nF; C_0603_1608Metric
C13: 4.7uF; C_0402_1005Metric
C14, C15, C16, C19, C20, C22, C23, C24, C25, C28, C29, C30, C32, C33, C34, C35, C38: 100nF; C_0402_1005Metric
C17: 1uF; C_0402_1005Metric
C18, C27, C31, C46: 4.7uF; C_0603_1608Metric
C21: 220nF; C_0603_1608Metric; LCSC C21120
C26, C36: 1uF; C_0603_1608Metric
C37, C39, C40, C41: 10pF; C_0402_1005Metric
C42, C43: 330pF; C_0402_1005Metric
D2: SS56; SMA_L4.3-W2.6-LS5.2-RD; LCSC Part C65009
D3: 15V; SOD-323_L1.7-W1.3-LS2.6-RD; LCSC Part C19077448
D4: 1N4148W; D_SOD-123
D5: LED; LED_0603_1608Metric; LCSC C965799
D6: LED; LED_0603_1608Metric; LCSC C19171301
D7: LED; LED_0603_1608Metric; LCSC C965807
D8, D9, D10, D11: LED; LED_0603_1608Metric; LCSC C965800
D12: LED; LED_0603_1608Metric; LCSC C2290
D13: PESD15VL1BA; D_SOD-323
FL1: MLPF-WB55-01E3; FILTER-SMD_6P-L1.6-W1.0-P0.50-BL; LCSC Part C2651048
H1, H2, H3, H4: MountingHole; MountingHole_2.2mm_M2
L1: FXL0530-4R7-M; IND-SMD_L5.4-W5.2_FXL0530; LCSC Part C177246
L2: 10uH; L_0603_1608Metric
L3: 10nH; L_0603_1608Metric
L4: 25X48MM_NFC_ANTENNA
Q1: IRFS7440TRLPBF; TO-263-2_L10.0-W9.1-P5.08-LS15.2-BR; LCSC Part C409762
Q2: 2SC1815_C727146; SOT-23-3_L2.9-W1.3-P1.90-LS2.4-BR; LCSC Part C727146
R1: 198.2K; R_0402_1005Metric; LCSC C3013157
R2: 2.28K; R_0402_1005Metric; LCSC C2998174
R3: 9.4K; R_0402_1005Metric; LCSC C852970
R4: 191K; R_0402_1005Metric; LCSC C2998070
R5: 30; R_0402_1005Metric
R6: 162K; R_0402_1005Metric
R7: 38K; R_0402_1005Metric; LCSC C852750
R8, R9, R10, R17, R37, R38, R40, R41: 10K; R_0402_1005Metric
R11, R19, R23, R25, R27, R28: 4.7K; R_0402_1005Metric
R12: 190K; R_0402_1005Metric; LCSC C2998070
R13: 9.5K; R_0402_1005Metric; LCSC C96273
R14, R16: 3.3K; R_0402_1005Metric
R15: 30.9K; R_0402_1005Metric
R18: HOLLR2512-3W-2MR-1%; RES-SMD_L6.4-W3.2-1; LCSC Part C2994640
R20: 100K; R_0402_1005Metric
R22: 1K; R_0402_1005Metric
R24, R29, R30, R31, R32, R33, R34, R35, R36: 100; R_0402_1005Metric
R26: 470; R_0402_1005Metric
R39: 400; R_0805_2012Metric; LCSC C153298
SW1: EC11E18244A5; SW-TH_EC11E18244A5; LCSC Part C255515
SW2, SW3: SW_Push; SW-SMD_L3.9-W3.0-P4.45; LCSC C720477
TP1, TP2, TP3: TestPoint; TestPoint_Pad_1.0x1.0mm
U1: TPS25730D; Texas_REF0038A_WQFN-38-2EP_6x4mm_P0.4
U2: TC4431EOA; SOIC-8_L4.9-W3.9-P1.27-LS6.0-BL; LCSC Part C2909520
U3: TPD6S300A; WQFN-20-1EP_3x3mm_P0.4mm_EP1.7x1.7mm_ThermalVias
U4, U11: DB128L-5.08-2P-BK-S; CONN-TH_2P-P5.08_DB128L-5.08-2P-BK-S; LCSC Part C430601
U5: INA226; VSSOP-10_3x3mm_P0.5mm
U6: TMP119AIYBGR; Texas_DSBGA-6_0.95x1.488mm_Layout2x3_P0.4mm
U8: W25Q256JVEIQTR; WSON-8_L8.0-W6.10-P1.27-BL-EP; LCSC Part C97522
U9: STM32WB55REVx; QFN-68-1EP_8x8mm_P0.4mm_EP6.4x6.4mm
U10: NT3H2111W0FHKH; XQFN-8_L1.6-W1.6-P0.50-BL_NT3H2111W0FHKH; LCSC Part C710403
U12: MAX31865xTP; TQFN-20-1EP_5x5mm_P0.65mm_EP3.25x3.25mm
U13: MAX6675ISA+T; SOIC-8_L5.0-W4.0-P1.27-LS6.0-BL; LCSC Part C16030
U14: DB128L-5.08-3P-BK-S; CONN-TH_3P-P5.08_DB128L-5.08-3P-BK-S; LCSC Part C430602
U15: TPS56339DDC; SOT-23-6
USB1: TYPE-C 16PIN 2MD(073); USB-C-SMD_TYPE-C-6PIN-2MD-073; LCSC Part C2765186
X1: XL7EL89CKI-111YLC-32M; CRYSTAL-SMD_4P-L2.0-W1.6-BL; LCSC Part C2965582
X2: X201232768KJD2SI; OSC-SMD_L2.0-W1.2; LCSC Part C383843

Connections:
+3.3V: BUZZER1.1, Brd1.2 (VCC), C10.1, C16.1, C19.1, C20.1, C21.2, C22.1, C23.1, C24.1, C25.1, C26.1, C27.1, C28.1, C29.1, C30.1, C31.1, C32.1, C33.1, C34.1, C35.1, C36.1, C44.1, C45.1, D4.1 (K), D13.2 (A), L1.1, R15.1, R19.1, R23.1, R25.1, R27.1, R28.1, R29.2, R30.2, R31.2, R32.2, R33.2, R34.2, R35.2, R36.2, R37.1, R38.1, R40.1, SW3.2, U1.38 (VIN_3V3), U5.6 (VS), U6.B1 (V+), U8.8 (VCC), U9.1 (VBAT), U9.13 (VREF+), U9.14 (VDDA), U9.30 (VDD), U9.33 (VDDRF), U9.44 (VDDSMPS), U9.45 (VDD), U9.55 (VDDUSB), U9.68 (VDD), U10.6 (VCC), U10.7 (VOUT), U12.19 (DVDD), U12.20 (VDD), U13.4 (VCC)
/ADCIN1: R1.2, R2.1, U1.2 (ADCIN1)
/ADCIN2: R3.2, R4.1, U1.3 (ADCIN2)
/ADCIN3: R6.2, R7.1, U1.5 (ADCIN3)
/ADCIN4: R12.2, R13.1, U1.7 (ADCIN4)
/BOOT: R41.2, SW3.1, U9.5 (PH3)
/BUTTON: SW1.D, U9.10 (PC1)
/BUZZER: R26.1, U9.23 (PA8)
/CAP_MIS: U1.6 (CAP_MIS), U9.51 (PA10)
/CC1: C42.1, U1.28 (CC1), U3.12 (CC1)
/CC2: C43.1, U1.29 (CC2), U3.11 (CC2)
/CURRENT_ALERT: R23.2, U5.3 (~Alert), U9.2 (PC13)
/C_CC1: U3.4 (C_CC1), U3.7 (RPD_G1), USB1.4 (CC1)
/C_CC2: U3.5 (C_CC2), U3.6 (RPD_G2), USB1.10 (CC2)
/DN: U3.20 (D1), U9.52 (PA11), USB1.5 (DN2), USB1.7 (DN1)
/DP: U3.19 (D2), U9.53 (PA12), USB1.6 (DP1), USB1.8 (DP2)
/DRAIN: U1.15 (DRAIN), U1.30 (DRAIN), U1.40 (DRAIN)
/ENC_A: R37.2, SW1.A, U9.9 (PC0)
/ENC_B: R38.2, SW1.B, U9.11 (PC2)
/FAULT_IN: R11.2, U1.18 (~FAULT_IN), U9.49 (PB15)
/FIELD_DETECT: R25.2, U9.26 (PC5), U10.4 (FD)
/FLASH_CLK: U8.6 (CLK), U9.18 (PA3)
/FLASH_CS: U8.1 (~CS), U9.17 (PA2)
/FLASH_IO0: U8.5 (DI(IO0)), U9.7 (PB9)
/FLASH_IO1: U8.2 (DO(IO1)), U9.6 (PB8)
/FLASH_IO2: U8.3 (WP#(IO2)), U9.22 (PA7)
/FLASH_IO3: U8.7 (HOLD#orRESET#(IO3)), U9.21 (PA6)
/HEATBED: R24.2, U9.15 (PA0)
/HXIN: C37.1, U9.35 (OSC_IN), X1.1
/HXOUT: C41.1, U9.34 (OSC_OUT), X1.3
/I2C_SCL: Brd1.3 (SCL), R27.2, U6.A2 (SCL), U9.28 (PB10), U10.3 (SCL)
/I2C_SDA: Brd1.4 (SDA), R28.2, U6.A1 (SDA), U9.29 (PB11), U10.5 (SDA)
/LED_BLUE: D7.1 (K), U9.38 (PB0)
/LED_COOLING: D11.1 (K), U9.58 (PC10)
/LED_GREEN: D6.1 (K), U9.39 (PB1)
/LED_PD: D12.1 (K), U9.62 (PD1)
/LED_PREHEAT: D8.1 (K), U9.61 (PD0)
/LED_RED: D5.1 (K), U9.40 (PE4)
/LED_REFLOW: D10.1 (K), U9.59 (PC11)
/LED_SOAK: D9.1 (K), U9.60 (PC12)
/LXIN: C39.1, U9.3 (PC14), X2.1 (OSC1)
/LXOUT: C40.1, U9.4 (PC15), X2.2 (OSC2)
/POWER_SCL: R14.2, U1.9 (I2Ct_SCL), U5.5 (SCL), U9.66 (PB6)
/POWER_SDA: R16.2, U1.8 (I2Ct_SDA), U5.4 (SDA), U9.67 (PB7)
/PT_CS: U9.19 (PA4), U12.13 (~CS)
/PT_DRDY: U9.25 (PC4), U12.18 (~DRDY)
/PT_MISO: U9.64 (PB4), U12.14 (SDO)
/PT_MOSI: U9.65 (PB5), U12.11 (SDI)
/PT_SCK: U9.63 (PB3), U12.12 (SCLK)
/RESET: R40.2, SW2.1, U9.8 (NRST)
/RF: FL1.3 (IN), U9.31 (RF1)
/SINK_EN: U1.19 (~SINK_EN), U9.50 (PC6)
/SWCLK: TP2.1, U9.56 (PA14)
/SWDIO: TP1.1, U9.54 (PA13)
/TEMP_ALERT: R19.2, U6.C2 (ALERT), U9.27 (PB2)
/THERMO_CS: U9.46 (PB12), U13.6 (~CS)
/THERMO_MISO: U9.48 (PB14), U13.7 (SO)
/THERMO_SCK: U9.47 (PB13), U13.5 (SCK)
GND: Brd1.1 (GND), C1.2, C2.2, C3.2, C4.2, C5.2, C6.2, C7.2, C8.2, C9.2, C10.2, C11.2, C12.2, C13.2, C15.2, C16.2, C17.2, C18.2, C19.2, C20.2, C21.1, C22.2, C23.2, C24.2, C25.2, C26.2, C27.2, C28.2, C29.2, C30.2, C31.2, C32.2, C33.2, C34.2, C35.2, C36.2, C37.2, C39.2, C40.2, C41.2, C42.2, C43.2, C44.2, C45.2, C46.2, C47.2, D3.2 (A), D13.1 (K), FL1.2 (GND4), FL1.4 (GND1), FL1.5 (GND2), FL1.6 (GND3), Q1.3 (S), Q2.2 (E), R2.2, R4.2, R7.2, R8.1, R9.1, R10.1, R13.2, R17.2, R22.2, R41.1, SW1.6, SW1.7, SW1.C, SW1.E, SW2.2, TP3.1, U1.11 (GND), U1.12 (GND), U1.14 (GND), U1.16 (GND), U1.17 (GND), U1.31 (GND), U1.34 (GND), U1.39 (GND), U2.3 (~LOCK_DIS), U2.4 (GND), U2.5 (GND), U3.8 (GND), U3.13 (GND), U3.16 (GND), U3.17 (GND), U3.18 (GND), U3.21 (GND), U5.1 (A1), U5.2 (A0), U5.7 (GND), U6.B2 (GND), U6.C1 (ADD0), U8.4 (GND), U8.9 (EP), U9.32 (VSSRF), U9.42 (VSSSMPS), U9.69 (VSS), U10.2 (VSS), U12.10 (GND), U12.15 (DGND), U12.16 (GND), U12.21 (GND), U13.1 (GND), U15.1 (GND), USB1.1 (GND), USB1.12 (GND), USB1.13 (SHELL), USB1.14 (SHELL), X1.2 (GND), X1.4 (GND)
LDO_1V5: C13.1, U1.4 (LDO_1V5)
LDO_3V3: C11.1, C17.1, R1.1, R3.1, R6.1, R11.1, R12.1, R14.1, R16.1, R20.1, U1.1 (LDO_3V3), U3.10 (VPWR)
unnamed: AE1.1 (ANT), FL1.1 (OUT)
unnamed: C14.1, R5.2
unnamed: D2.2 (A), Q1.4 (D), U4.2
unnamed: D3.1 (K), Q1.1 (G), R22.1, U2.6 (~OUT), U2.7 (~OUT)
unnamed: BUZZER1.2, D4.2 (A), Q2.3 (C)
unnamed: D5.2 (A), R29.1
unnamed: D6.2 (A), R30.1
unnamed: D7.2 (A), R31.1
unnamed: D8.2 (A), R32.1
unnamed: D9.2 (A), R33.1
unnamed: D10.2 (A), R34.1
unnamed: D11.2 (A), R35.1
unnamed: D12.2 (A), R36.1
unnamed: L2.1, L3.2
unnamed: Q2.1 (B), R26.2
unnamed: R8.2, U1.26 (RESERVED)
unnamed: R9.2, U1.27 (RESERVED)
unnamed: R10.2, U1.36 (RESERVED)
unnamed: R24.1, U2.2 (IN)
unnamed: C15.1, U3.3 (VBIAS)
unnamed: R20.2, U3.9 (~FLT)
unnamed: C18.1, L2.2, U9.41 (VFBSMPS)
unnamed: L3.1, U9.43 (VLXSMPS)
unnamed: L4.1, U10.1 (LA)
unnamed: L4.2, U10.8 (LB)
unnamed: R39.1, U12.1 (BIAS), U12.2 (REFIN+)
unnamed: U12.5 (FORCE+), U12.6 (FORCE2), U14.3
unnamed: C38.2, U12.8 (RTDIN-), U12.9 (FORCE-), U14.1
unnamed: R39.2, U12.3 (REFIN-), U12.4 (ISENSOR)
unnamed: C38.1, U12.7 (RTDIN+), U14.2
unnamed: U11.1, U13.3 (T+)
unnamed: U11.2, U13.2 (T-)
unnamed: R5.1, U15.6 (BOOT)
unnamed: R15.2, R17.1, U15.4 (FB)
unnamed: C14.2, L1.2, U15.2 (SW)
PPHV: C3.1, C6.1, C12.1, C46.1, C47.1, D2.1 (K), R18.1, U2.1 (VDD), U2.8 (VDD), U4.1, U5.8 (Vbus), U5.9 (Vin-), U15.3 (VIN)
PPHV_R: C2.1, C5.1, C8.1, R18.2, U1.20 (PPHV), U5.10 (Vin+)
VBUS: C1.1, C4.1, C7.1, C9.1, U1.23 (VBUS_IN), U1.32 (VBUS), USB1.2 (VBUS), USB1.11 (VBUS)

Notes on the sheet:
I/O
EXTERNAL TEMPERATURE SENSORS
PERIPHERALS
EMBER
BUZZER AND LEDS
USB-C
100Ω RTD = 100nF 1kΩ RTD = 10nF
USB ESD
USB-C PD
Value: 7
Value: 1
BOARD TEMP SENSOR
DECOUPLING
NFC
32MB FLASH
CURRENT SENSOR
ADDRESS: 0x40
3V3 BUCK CONVERTER
ADDRESS: 1001000x
HEATBED CONTROL
Value: 0
I2C ADDRESS: 0x20
STM32
Value: 3

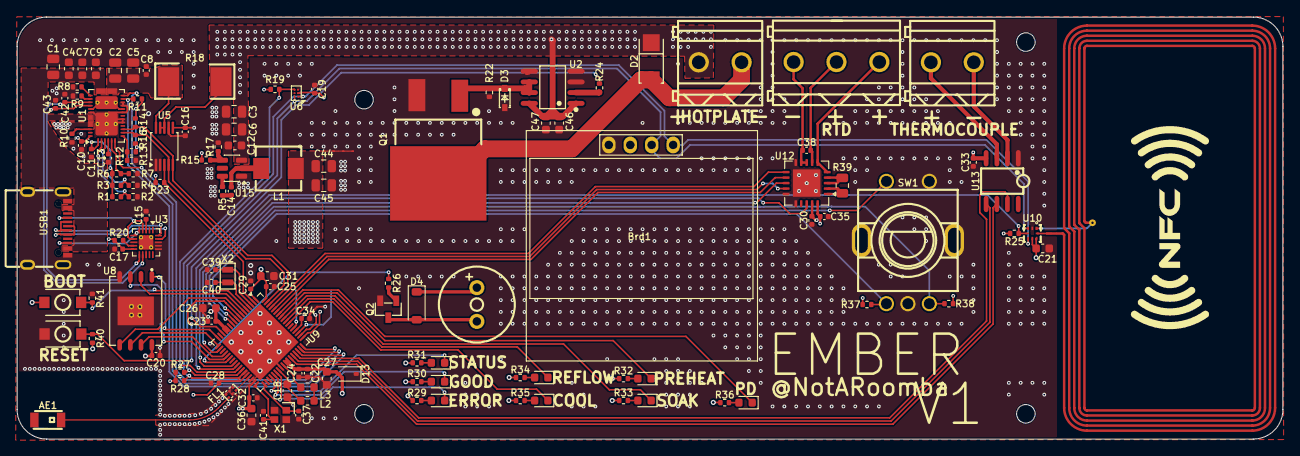
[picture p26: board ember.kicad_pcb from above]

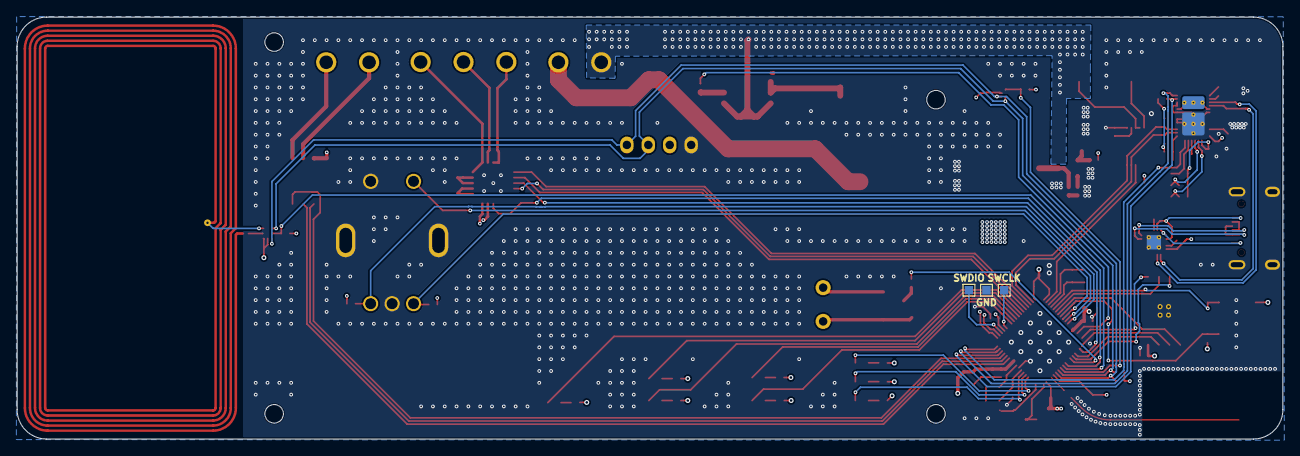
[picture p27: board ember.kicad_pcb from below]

Board: 4 copper layers, 150.0 x 50.0 mm, 136 parts (3 on the bottom side), 97 nets.

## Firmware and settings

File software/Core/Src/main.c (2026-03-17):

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
/* Includes ------------------------------------------------------------------*/
#include "main.h"
#include "usb_device.h"

/* USER CODE BEGIN Includes */

#include "config.h"
#include "utils.h"
#include "tps25730_driver.h"
#include "speaker.h"
#include "input.h"
#include "heater.h"
#include "tmp116.h"
#include "nfc.h"
#include "driver_ina226_basic.h"

#include "rtd.h"

#include "thermocouple.h"

#include "swallow2.h"

#define SSD1306_BLENDER_PRO_BOLD_FONT_13x19

#include "ssd1306.h"
#include "ssd1306_tests.h"
#include <stdlib.h>
#include "ui.h"
#include "blenderProBold.h"
#include "fonts.h"
/* USER CODE END Includes */

I2C_HandleTypeDef hi2c1;
I2C_HandleTypeDef hi2c3;
DMA_HandleTypeDef hdma_i2c3_tx;

IPCC_HandleTypeDef hipcc;

LPTIM_HandleTypeDef hlptim1;

QSPI_HandleTypeDef hqspi;

RTC_HandleTypeDef hrtc;

SPI_HandleTypeDef hspi1;
SPI_HandleTypeDef hspi2;

TIM_HandleTypeDef htim1;
TIM_HandleTypeDef htim2;

/* USER CODE BEGIN PV */
TPS25730_Handle *tps_handle = NULL;
Speaker_Handle *speaker = NULL;
TMP116_Handle_t tmp116;
static uint32_t last_temp_read = 0;

static uint32_t last_tc_poll = 0;
static uint32_t last_nfc_poll = 0;
static uint32_t last_ina226_poll = 0;
// Encoder tone settings (configurable)
static uint32_t encoder_tone_base_freq = 2093; // C7
static int16_t encoder_tone_steps = 0; // steps from base, CCW +1 => +50Hz
static uint32_t encoder_tone_step_hz = 50; // Hz per step
static uint32_t encoder_tone_current_freq = 2093; // Start at base freq

/* Random teleport variables for SSD1306 */
static uint32_t last_teleport = 0;
static const uint32_t TELEPORT_INTERVAL_MS = 300; // teleport interval
static const uint8_t TELEPORT_RADIUS = 10; // circle radius

// Forward-declare menu callback
static void main_menu_select_cb(uint8_t idx, void *ctx);

// Settings screen state and helpers
static volatile bool settings_active = false;
static volatile int settings_heater_percent = 0;
static void settings_show(void);
static void settings_update_display(void);
static void settings_on_ok(void *ctx);

SSD1306_t SSD1306_Disp;
/* USER CODE END PV */

void SystemClock_Config(void);
void PeriphCommonClock_Config(void);
static void MX_GPIO_Init(void);
static void MX_DMA_Init(void);
static void MX_I2C1_Init(void);
static void MX_I2C3_Init(void);
static void MX_QUADSPI_Init(void);
static void MX_SPI2_Init(void);
static void MX_TIM1_Init(void);
static void MX_TIM2_Init(void);
static void MX_LPTIM1_Init(void);
static void MX_SPI1_Init(void);
static void MX_IPCC_Init(void);
static void MX_RTC_Init(void);
static void MX_RF_Init(void);
/* USER CODE BEGIN PFP */
/**
  * @brief Callback for main menu selections
  * @param idx: Index of the selected item
  * @param ctx: Context pointer (ui_menu_t *)
  * @retval None
  */
static void main_menu_select_cb(uint8_t idx, void *ctx) {
    ui_menu_t *m = (ui_menu_t *)ctx;
    switch (idx) {
        case 0: // Home
            ui_show_home(m);
            break;
        case 1: { // Status - show USB-C PD voltage & amperage + temperature
            static char status_buf[128];
            int len = 0;
            if (tps_handle != NULL) {
                uint32_t voltage_mv = 0, current_ma = 0;
                if (TPS25730_GetActiveVoltage(tps_handle, &voltage_mv, &current_ma)) {
                    uint32_t volts = voltage_mv / 1000;
                    uint32_t vfrac = (voltage_mv % 1000) / 10; // hundredths
                    uint32_t amps_int = current_ma / 1000;
                    uint32_t amps_frac = (current_ma % 1000) / 10; // hundredths
                    len = snprintf(status_buf, sizeof(status_buf), "%lu.%02lu V\n%lu.%02lu A (%lumA)", volts, vfrac, amps_int, amps_frac, current_ma);
                } else {
                    len = snprintf(status_buf, sizeof(status_buf), "USB-C PD: unavailable");
                }
            } else {
                len = snprintf(status_buf, sizeof(status_buf), "USB-C PD: not initialized");
            }
            if (len < 0) len = 0;
            if (len > (int)sizeof(status_buf) - 1) len = sizeof(status_buf) - 1;

            float temperature;
            if (TMP116_GetTemperature(&tmp116, &temperature) == TMP116_OK) {
                int rem = (int)sizeof(status_buf) - len;
                if (rem > 1) {
                    int n = snprintf(status_buf + len, rem, "\nTemp: %.2f C", temperature);
                    if (n > 0) len += n;
                }
            } else {
                int rem = (int)sizeof(status_buf) - len;
                if (rem > 1) {
                    int n = snprintf(status_buf + len, rem, "\nTemp: N/A");
                    if (n > 0) len += n;
                }
            }

            ui_show_text("Status", status_buf, &Font_11x18, &Font_6x8, NULL, NULL);
            break;
        }
        case 2: // Settings
            settings_show();
            break;
        case 3: // About
            ui_show_text("About", "Ember V1\n@NotARoomba", &Font_11x18, &Font_6x8, NULL, NULL);
            break;
        default:
            break;
    }
}
/* USER CODE END PFP */

/* USER CODE BEGIN 0 */

// Static buffer used by settings UI so the pointer remains valid
static char settings_buf[128];

// Show the settings screen and initialize value from current heater percent
static void settings_show(void) {
    settings_heater_percent = (int)(Heater_GetPercent() + 0.5f);
    snprintf(settings_buf, sizeof(settings_buf), "Heater: %d%%\nShort press to save\nLong press to return", settings_heater_percent);
    ui_show_text("Settings", settings_buf, &Font_11x18, &Font_6x8, settings_on_ok, NULL);
    settings_active = true;
}

// Update the displayed text - update current text screen in-place
static void settings_update_display(void) {
    snprintf(settings_buf, sizeof(settings_buf), "Heater: %d%%\nShort press to save\nLong press to return", settings_heater_percent);
    ui_update_text(settings_buf);
}

// Save callback (short press) - apply and close
static void settings_on_ok(void *ctx) {
    (void)ctx;
    print("Settings: Heater set to %d%%\r\n", settings_heater_percent);
    Heater_SetPercent((float)settings_heater_percent);
    settings_active = false;
    // Close the settings screen
    ui_handle_event(UI_EVT_BACK);
}

/* USER CODE END 0 */

/**
  * @brief  The application entry point.
  * @retval int
  */
int main(void)
{

  /* MCU Configuration--------------------------------------------------------*/

  /* Reset of all peripherals, Initializes the Flash interface and the Systick. */
  HAL_Init();
  /* Config code for STM32_WPAN (HSE Tuning must be done before system clock configuration) */
  MX_APPE_Config();

  /* Configure the system clock */
  SystemClock_Config();

  /* Configure the peripherals common clocks */
  PeriphCommonClock_Config();

  /* IPCC initialisation */
  MX_IPCC_Init();

  /* Initialize all configured peripherals */
  MX_GPIO_Init();
  MX_DMA_Init();
  MX_I2C1_Init();
  MX_I2C3_Init();
  MX_QUADSPI_Init();
  MX_SPI2_Init();
  MX_TIM1_Init();
  MX_TIM2_Init();
  MX_LPTIM1_Init();
  MX_SPI1_Init();
  MX_USB_Device_Init();
  MX_RTC_Init();
  MX_RF_Init();
  /* USER CODE BEGIN 2 */
  
  HAL_Delay(1000);

  /* Prevent unused-variable warnings until poll code is enabled */
  (void)last_temp_read;
  (void)last_ina226_poll;

  /* Scan I2C3 bus for devices */
  // int i2c3_devices = I2C_ScanBus(&hi2c3);
  // print("I2C3: %d device(s) found\r\n", i2c3_devices);

  /* Register LED pins with utils so Update_LEDs can control them */
  LEDs_RegisterPin(LED_STATUS_PD,       LED_PD_GPIO_Port,       LED_PD_Pin);
  LEDs_RegisterPin(LED_STATUS_PREHEAT,  LED_PREHEAT_GPIO_Port,  LED_PREHEAT_Pin);
  LEDs_RegisterPin(LED_STATUS_SOAK,     LED_SOAK_GPIO_Port,     LED_SOAK_Pin);
  LEDs_RegisterPin(LED_STATUS_REFLOW,   LED_REFLOW_GPIO_Port,   LED_REFLOW_Pin);
  LEDs_RegisterPin(LED_STATUS_COOL,     LED_COOLING_GPIO_Port,  LED_COOLING_Pin);
  LEDs_RegisterPin(LED_STATUS_STATUS,   LED_BLUE_GPIO_Port,    LED_BLUE_Pin);
  LEDs_RegisterPin(LED_STATUS_GOOD,     LED_GREEN_GPIO_Port,     LED_GREEN_Pin);
  LEDs_RegisterPin(LED_STATUS_ERROR,    LED_RED_GPIO_Port,      LED_RED_Pin);

  /* Set blink interval (ms) and start blinking all LEDs for visual test */
  LEDs_SetBlinkInterval(500);
  LEDs_Blinking();
  
  // Initialize input handling (encoder + button)
  if (!Input_Init()) {
    print("Input: Init FAILED\r\n");
    Error_Handler();
  }
  
  // Initialize heater PWM control
  Heater_Init();
  // Heater_Off();

  Heater_SetPercent(0);

  // Initialize TMP119 temperature sensor on I2C3
  if (TMP116_Init(&tmp116, &hi2c3, TMP116_I2C_ADDRESS) == TMP116_OK) {
    print("TMP119: OK\r\n");
  } else {
    print("TMP119: FAILED\r\n");
  }
  

  // Initialize NT3H2111 NFC tag on I2C3
  if (NFC_Init() == NFC_OK) {
    // NFC_DisablePasswordProtection();
    // Factory reset NFC tag after init using NFC wrapper
    // if (NFC_FactoryReset() == NFC_OK) {
    //   print("NFC: Factory reset complete\r\n");
    // } else {
    //   print("NFC: Factory reset FAILED\r\n");
    // }
    // // NFC_WriteText("Ember V1 NFC Tag");
    NFC_RefreshHash();  // Sync hash with current memory state
  }

  print("Ember V1!\r\n");
  
  // Initialize TPS25730 on I2C1 (assuming address 0x20)
  tps_handle = TPS25730_Init(&hi2c1, 0x20);
  if (tps_handle == NULL) {
    print("TPS25730: Init FAILED\r\n");
  }
  
  HAL_Delay(250);
  
  if (tps_handle != NULL) {
    uint32_t voltage_mv, current_ma;
    
    /*
    // === List all available PDOs from charger ===
    TPS25730_SourceCaps source_caps;
    if (TPS25730_ReadRxSourceCaps(tps_handle, &source_caps)) {
      print("=== Source PDOs ===\r\n");
      for (uint8_t i = 0; i < source_caps.num_valid_pdos; i++) {
        uint32_t pdo = source_caps.pdos[i];
        TPS25730_FixedPDO fixed;
        if (TPS25730_ParseFixedPDO(pdo, &fixed)) {
          print("PDO %u: %lu.%02luV @ %lu.%02luA\r\n", i+1, 
                fixed.voltage_mv/1000, (fixed.voltage_mv%1000)/10,
                fixed.operational_current_ma/1000, (fixed.operational_current_ma%1000)/10);
        }
      }
    }
    */
    
    // Get current voltage
    if (TPS25730_GetActiveVoltage(tps_handle, &voltage_mv, &current_ma)) {
      print("Current: %lu.%02luV @ %lu.%02luA\r\n", 
            voltage_mv/1000, (voltage_mv%1000)/10,
            current_ma/1000, (current_ma%1000)/10);
    }
    
    // Request 20V @ 5A
    print("Requesting 20V @ 5A...\r\n");
    if (TPS25730_RequestVoltage(tps_handle, 20000, 5000, 5000)) {
      HAL_Delay(250);
      
      // Get updated voltage
      if (TPS25730_GetActiveVoltage(tps_handle, &voltage_mv, &current_ma)) {
        print("Updated: %lu.%02luV @ %lu.%02luA\r\n", 
              voltage_mv/1000, (voltage_mv%1000)/10,
              current_ma/1000, (current_ma%1000)/10);
      }
    } else {
      print("Request failed\r\n");
    }
  }

  // Initialize speaker and play jingle bells
  speaker = Speaker_Init(&htim1, TIM_CHANNEL_1, 64000000);
  
  // Jingle Bells melody
  // const Speaker_Note jingle_bells[] = {
  //   // "Jingle bells, jingle bells"
  //   {NOTE_E5, 200}, {NOTE_E5, 200}, {NOTE_E5, 400},
  //   {NOTE_E5, 200}, {NOTE_E5, 200}, {NOTE_E5, 400},
  //   // "Jingle all the way"
  //   {NOTE_E5, 200}, {NOTE_G5, 200}, {NOTE_C5, 200}, {NOTE_D5, 200}, {NOTE_E5, 600},
  //   {NOTE_REST, 200},
  //   // "Oh what fun it is to ride"
  //   {NOTE_F5, 200}, {NOTE_F5, 200}, {NOTE_F5, 200}, {NOTE_F5, 200},
  //   {NOTE_F5, 200}, {NOTE_E5, 200}, {NOTE_E5, 200}, {NOTE_E5, 100}, {NOTE_E5, 100},
  //   // "In a one horse open sleigh"
  //   {NOTE_E5, 200}, {NOTE_D5, 200}, {NOTE_D5, 200}, {NOTE_E5, 200}, {NOTE_D5, 400}, {NOTE_G5, 400},
  // };
  
  // Speaker_PlayMelody(speaker, jingle_bells, sizeof(jingle_bells)/sizeof(jingle_bells[0]));
  
  // // Wait for melody to finish
  // while (Speaker_Update(speaker)) {
  //   // Melody still playing
  // }



  // Initialize INA226 on I2C1 (bus voltage/current monitor)
  // 3W 2mΩ SMD ±50ppm/℃ Current Sense Resistor ±1% 2512
  // if (ina226_basic_init(INA226_ADDRESS_0, 0.002) == 0) {
  //   print("INA226: OK\r\n");
  // } else {
  //   print("INA226: FAILED\r\n");
  // }


  // Initialize RTD (MAX31865) on SPI1
  RTD_Init();
  print("RTD: MAX31865 initialized\r\n");

  // Initialize Thermocouple (MAX6675) on SPI2
  Thermocouple_Init();
  print("Thermocouple: MAX6675 initialized\r\n");

    LEDs_Off();
    Set_LED_Status(LED_STATUS_GOOD, ON);
    Set_LED_Status(LED_STATUS_PD, BLINKING);
    // u8g2_Setup_ssd1306_i2c_128x64_noname_1();
    ssd1306_Init();

    // Initialize UI
    ui_init();
    static const char *main_menu_items[] = {"Home", "Status", "Settings", "About"};
    static ui_menu_t main_menu; // initialize at runtime to allow Font_7x10 assignment
    main_menu.items = main_menu_items;
    main_menu.count = sizeof(main_menu_items)/sizeof(main_menu_items[0]);
    main_menu.selected = 0;
    main_menu.top = 0;
    main_menu.lines = 4;
    main_menu.left_padding = 2;
    main_menu.right_padding = 2;
    // select the preferred font: try Minecraft 8x10 first, then configured default
    main_menu.font = &fontBlenderProBold18pt13x19;
    // main_menu.title = "Main Menu";
    main_menu.on_select = main_menu_select_cb;
    main_menu.cb_ctx = &main_menu;
    // Show the branded home screen and allow the user to press OK to enter the main menu
    ui_show_home(&main_menu);

    // ssd1306_TestAll();

 
    // HAL_Delay(500);
    // ssd1306_FillCircle(64, 32, 10, White);
    // ssd1306_UpdateScreen();
    // HAL_Delay(500);
    // ssd1306_FillCircle(64, 32, 10, White);
    // ssd1306_UpdateScreen();
    // ssd1306_FillCircle(64, 32, 10, White);
    // ssd1306_UpdateScreen();
  /* USER CODE END 2 */

  /* Init code for STM32_WPAN */
  MX_APPE_Init();

  /* Infinite loop */
  /* USER CODE BEGIN WHILE */
  while (1)
  {
    // Poll inputs (non-blocking)
    Input_Poll();
    Update_LEDs();
    Speaker_Update(speaker);

    // Poll Thermocouple (MAX6675) for temperature every 500ms
    if ((HAL_GetTick() - last_tc_poll) >= 500) {
      last_tc_poll = HAL_GetTick();
       float tc_temp = Thermocouple_ReadCelsius();
      if (Thermocouple_Ok()) {
        print("Thermocouple: %.2f C\r\n", tc_temp);
      } else {
        print("Thermocouple: read failed\r\n");
      }
    }

    // let UI process events and redraw when ready
    ui_tick();

    // Random teleport – only attempt when no UI screen is active
    if (!ui_is_active() && (int32_t)(HAL_GetTick() - last_teleport) >= (int32_t)TELEPORT_INTERVAL_MS) {
        if (SSD1306_Disp.state == SSD1306_STATE_READY) {
            last_teleport = HAL_GetTick();
            ssd1306_Fill(Black); // clear buffer
            uint8_t x = (uint8_t)(rand() % (SSD1306_WIDTH - 2*TELEPORT_RADIUS)) + TELEPORT_RADIUS;
            uint8_t y = (uint8_t)(rand() % (SSD1306_HEIGHT - 2*TELEPORT_RADIUS)) + TELEPORT_RADIUS;
            ssd1306_FillCircle(x, y, TELEPORT_RADIUS, White);
            ssd1306_UpdateScreen();
        }
    }

    // Handle encoder events
    if (input_encoder_cw) {
      input_encoder_cw = false;

      if (settings_active) {
          // Counter-clockwise -> increase percentage
          if (settings_heater_percent < 100) settings_heater_percent++;
          settings_update_display();
          print("Settings: Heater %d%%\r\n", settings_heater_percent);
          // if (speaker != NULL) { Speaker_Beep(speaker, 1000, 30, 10, 1); }
      } else {
          // Notify UI (rotary clockwise -> DOWN)
          ui_handle_event(UI_EVT_DOWN);

          print("Encoder CW, position: %ld\r\n", input_encoder_position);
          // Decrease pitch by 50 Hz per clockwise step
          // encoder_tone_steps--;
          // int32_t freq = (int32_t)encoder_tone_base_freq + (int32_t)encoder_tone_steps * (int32_t)encoder_tone_step_hz;
          // if (freq < 20) freq = 20;
          // if (freq > 20000) freq = 20000;
          // encoder_tone_current_freq = (uint32_t)freq;
          // if (speaker != NULL) {
          //   Speaker_Beep(speaker, (uint16_t)freq, 30, 10, 1);
          // }
      }
    }
    if (input_encoder_ccw) {
      input_encoder_ccw = false;

      if (settings_active) {
          // Clockwise -> decrease percentage
          if (settings_heater_percent > 0) settings_heater_percent--;
          settings_update_display();
          print("Settings: Heater %d%%\r\n", settings_heater_percent);
          // if (speaker != NULL) { Speaker_Beep(speaker, 1200, 30, 10, 1); }
      } else {
          // Notify UI (rotary counter-clockwise -> UP)
          ui_handle_event(UI_EVT_UP);

          print("Encoder CCW, position: %ld\r\n", input_encoder_position);
          // Increase pitch by 50 Hz per counter-clockwise step
          // encoder_tone_steps++;
          // int32_t freq = (int32_t)encoder_tone_base_freq + (int32_t)encoder_tone_steps * (int32_t)encoder_tone_step_hz;
          // if (freq < 20) freq = 20;
          // if (freq > 20000) freq = 20000;
          // encoder_tone_current_freq = (uint32_t)freq;
          // if (speaker != NULL) {
          //   Speaker_Beep(speaker, (uint16_t)freq, 30, 10, 1);
          // }
      }
    }

    // Handle button events
    if (input_button_pressed) {
      input_button_pressed = false;
      // Notify UI (button press -> OK/select)
      ui_handle_event(UI_EVT_OK);

      print("Button short press! Position: %ld\r\n", input_encoder_position);
      // if (speaker != NULL) {
      //   // Play current beep and print frequency
      //   // Speaker_Beep(speaker, (uint16_t)encoder_tone_current_freq, 40, 10, 1);
      //   // print("Speaker current beep: %lu Hz\r\n", encoder_tone_current_freq);
      //     Speaker_PlayMelody(speaker, swallow, sizeof(swallow)/sizeof(swallow[0]));
      //   while(Speaker_Update(speaker)) {
          
      //   }
      }
      // TODO: Handle short press (e.g., select/confirm)
    
    if (input_button_long_pressed) {
      input_button_long_pressed = false;
      if (settings_active) {
          settings_active = false;
          ui_handle_event(UI_EVT_BACK);
          print("Settings: canceled\r\n");
      } else {
        ui_handle_event(UI_EVT_BACK);
          print("Button long press!\r\n");
          // TODO: Additional global long-press behavior
      }
    }
    // Poll temperature sensor periodically
    // if ((HAL_GetTick() - last_temp_read) >= TEMP_READ_INTERVAL_MS) {
    //   last_temp_read = HAL_GetTick();
    //   float temperature;
    //   if (TMP116_GetTemperature(&tmp116, &temperature) == TMP116_OK) {
    //     print("Temp: %d.%02d C\r\n", (int)temperature, (int)((temperature - (int)temperature) * 100));
    //   }
    // }
    
    // Poll NFC for field detection and data changes
    if ((HAL_GetTick() - last_nfc_poll) >= NFC_POLL_INTERVAL_MS) {
      last_nfc_poll = HAL_GetTick();
      NFC_Events_t nfc_events;
      if (NFC_Poll(&nfc_events) == NFC_OK) {
        Set_LED_Status(LED_STATUS_STATUS, nfc_events.field_detected ? ON : OFF);
        //play a jingle  c4 and then f4 in sequence
        
        if (nfc_events.data_changed) {
                        Speaker_PlayMelody(speaker, (Speaker_Note[]){ {NOTE_F4, 75}, {NOTE_C4, 50} }, 2);

          // Read first 16 bytes of user memory to see what changed
          uint8_t nfc_data[16];
          char nfc_text[128];
          if (NFC_ReadMemory(0, nfc_data, sizeof(nfc_data)) == NFC_OK) {
            for (size_t i = 0; i < sizeof(nfc_data); i++) {
              print("%02x ", nfc_data[i]);
            }
            print("\r\n");
          }
        if (NFC_ReadText(nfc_text, sizeof(nfc_text)) == NFC_OK) {
          print("NFC Text: %s\r\n", nfc_text);
        }
        } else if  (nfc_events.field_detected) {
              // Field detected - play C4
              Speaker_PlayMelody(speaker, (Speaker_Note[]){ {NOTE_C4, 75}, {NOTE_F4, 50} }, 2);
            }

      }
    }
    // Poll INA226 for current/voltage every 500ms
    // if ((HAL_GetTick() - last_ina226_poll) >= 500) {
    //   last_ina226_poll = HAL_GetTick();
    //   float bus_mv = 0, current_ma = 0, power_mw = 0;
    //   if (ina226_basic_read(&bus_mv, &current_ma, &power_mw) == 0) {
    //     print("INA226: %.2f mV, %.2f mA, %.2f mW\r\n", bus_mv, current_ma, power_mw);
    //   } else {
    //     print("INA226: read failed\r\n");
    //   }
    // }
    

    // Poll RTD (MAX31865) for temperature every 500ms
    // static uint32_t last_rtd_poll = 0;
    // if ((HAL_GetTick() - last_rtd_poll) >= 500) {
    //   last_rtd_poll = HAL_GetTick();
    //   float rtd_temp = RTD_ReadCelsius();
    //   float rtd_ohms = RTD_ReadOhms();
    //   if (!RTD_Fault()) {
    //     print("RTD: %.2f C, %.2f Ohms\r\n", rtd_temp, rtd_ohms);
    //   } else {
    //     print("RTD: FAULT (code 0x%02X)\r\n", RTD_FaultCode());
    //     RTD_ClearFault();
    //   }
    // }


    
    // Other main loop tasks here...
    
    /* USER CODE END WHILE */
    MX_APPE_Process();

    /* USER CODE BEGIN 3 */
  }
  /* USER CODE END 3 */
}

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


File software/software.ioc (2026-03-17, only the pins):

Mcu.UserName=STM32WB55REVx
PA0.GPIO_Label=HEATBED
PA0.Signal=S_TIM2_CH1
PA11.Signal=USB_DM
PA12.Signal=USB_DP
PA13.Signal=SYS_JTMS-SWDIO
PA14.Signal=SYS_JTCK-SWCLK
PA2.Signal=QUADSPI_BK1_NCS
PA3.Signal=QUADSPI_CLK
PA4.GPIO_Label=PT_CS
PA4.Signal=SPI1_NSS
PA6.Signal=QUADSPI_BK1_IO3
PA7.Signal=QUADSPI_BK1_IO2
PA8.GPIO_Label=BUZZER
PA8.Signal=S_TIM1_CH1
PB0.GPIO_Label=LED_BLUE
PB0.Signal=GPIO_Output
PB1.GPIO_Label=LED_GREEN
PB1.Signal=GPIO_Output
PB10.GPIO_Label=I2C_SCL
PB10.Signal=I2C3_SCL
PB11.GPIO_Label=I2C_SDA
PB11.Signal=I2C3_SDA
PB12.GPIO_Label=THERMO_CS
PB12.Signal=SPI2_NSS
PB13.GPIO_Label=THERMO_SCK
PB13.Signal=SPI2_SCK
PB14.GPIO_Label=THERMO_MISO
PB14.Signal=SPI2_MISO
PB15.GPIO_Label=FAULT_IN
PB15.Signal=GPIO_Input
PB2.GPIO_Label=TEMP_ALERT
PB2.Signal=GPXTI2
PB3.GPIO_Label=PT_SCK
PB3.Signal=SPI1_SCK
PB4.GPIO_Label=PT_MISO
PB4.Signal=SPI1_MISO
PB5.GPIO_Label=PT_MOSI
PB5.Signal=SPI1_MOSI
PB6.GPIO_Label=POWER_SCL
PB6.Signal=I2C1_SCL
PB7.GPIO_Label=POWER_SDA
PB7.Signal=I2C1_SDA
PB8.Signal=QUADSPI_BK1_IO1
PB9.Signal=QUADSPI_BK1_IO0
PC0.GPIO_Label=ENC_A
PC0.Signal=LPTIM1_IN1
PC1.GPIO_Label=BUTTON
PC1.Signal=GPIO_Input
PC10.GPIO_Label=LED_COOLING
PC10.Signal=GPIO_Output
PC11.GPIO_Label=LED_REFLOW
PC11.Signal=GPIO_Output
PC12.GPIO_Label=LED_SOAK
PC12.Signal=GPIO_Output
PC13.GPIO_Label=CURRENT_ALERT
PC13.Signal=GPXTI13
PC14-OSC32_IN.Signal=RCC_OSC32_IN
PC15-OSC32_OUT.Signal=RCC_OSC32_OUT
PC2.GPIO_Label=ENC_B
PC2.Signal=LPTIM1_IN2
PC4.GPIO_Label=PT_DRDY
PC4.Signal=GPXTI4
PC5.GPIO_Label=FIELD_DETECT
PC5.Signal=GPIO_Input
PC6.GPIO_Label=SINK_EN
PC6.Signal=GPIO_Input
PD0.GPIO_Label=LED_PREHEAT
PD0.Signal=GPIO_Output
PD1.GPIO_Label=LED_PD
PD1.Signal=GPIO_Output
PE4.GPIO_Label=LED_RED
PE4.Signal=GPIO_Output

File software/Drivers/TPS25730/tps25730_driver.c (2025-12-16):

/**
 ******************************************************************************
 * @file    driver.c
 * @brief   TPS25730 USB PD Controller Driver Implementation
 * @author  Generated from TPS25730 Technical Reference Manual
 * @date    December 16, 2025
 ******************************************************************************
 */

#include "tps25730_driver.h"
#include <string.h>
#include <stdlib.h>
#include <stm32wbxx_hal_i2c.h>

/* I2C Timeout */
#define TPS25730_I2C_TIMEOUT    100

/* Helper macros for bit manipulation */
#define BIT_MASK(bits)          ((1U << (bits)) - 1)
#define GET_BITS(val, pos, bits) (((val) >> (pos)) & BIT_MASK(bits))
#define SET_BITS(val, pos, bits, data) \
    ((val) = ((val) & ~(BIT_MASK(bits) << (pos))) | (((data) & BIT_MASK(bits)) << (pos)))

/* PDO voltage/current conversion macros */
#define VOLTAGE_TO_PDO(mv)      ((mv) / 50)     // Convert mV to 50mV units
#define PDO_TO_VOLTAGE(units)   ((units) * 50)  // Convert 50mV units to mV
#define CURRENT_TO_PDO(ma)      ((ma) / 10)     // Convert mA to 10mA units
#define PDO_TO_CURRENT(units)   ((units) * 10)  // Convert 10mA units to mA
#define POWER_TO_PDO(mw)        ((mw) / 250)    // Convert mW to 250mW units
#define PDO_TO_POWER(units)     ((units) * 250) // Convert 250mW units to mW

/* PPS conversion macros */
#define PPS_VOLTAGE_TO_PDO(mv)      ((mv) / 100)     // Convert mV to 100mV units
#define PPS_PDO_TO_VOLTAGE(units)   ((units) * 100)  // Convert 100mV units to mV
#define PPS_CURRENT_TO_PDO(ma)      ((ma) / 50)      // Convert mA to 50mA units
#define PPS_PDO_TO_CURRENT(units)   ((units) * 50)   // Convert 50mA units to mA

/* Private function prototypes */
static bool TPS25730_ReadRegister(TPS25730_Handle *handle, uint8_t reg_addr, 
                                  uint8_t *data, uint16_t length);
static bool TPS25730_WriteRegister(TPS25730_Handle *handle, uint8_t reg_addr, 
                                   const uint8_t *data, uint16_t length);

/**
 * @brief Initialize TPS25730 driver
 * @param hi2c: Pointer to I2C handle
 * @param device_address: 7-bit I2C device address
 * @return Pointer to initialized handle, or NULL on error
 */
TPS25730_Handle* TPS25730_Init(I2C_HandleTypeDef *hi2c, uint8_t device_address)
{
    if (hi2c == NULL) {
        return NULL;
    }

    TPS25730_Handle *handle = (TPS25730_Handle*)malloc(sizeof(TPS25730_Handle));
    if (handle == NULL) {
        return NULL;
    }

    handle->hi2c = hi2c;
    handle->device_address = device_address << 1; // Convert to 8-bit address

    return handle;
}

/**
 * @brief Deinitialize TPS25730 driver
 * @param handle: Pointer to driver handle
 * @return true if successful
 */
bool TPS25730_DeInit(TPS25730_Handle *handle)
{
    if (handle != NULL) {
        free(handle);
        return true;
    }
    return false;
}

/**
 * @brief Read received source capabilities from charger
 * @param handle: Pointer to driver handle
 * @param caps: Pointer to store source capabilities
 * @return true if successful
 */
bool TPS25730_ReadRxSourceCaps(TPS25730_Handle *handle, TPS25730_SourceCaps *caps)
{
    uint8_t buffer[29];
    
    if (handle == NULL || caps == NULL) {
        return false;
    }

    if (!TPS25730_ReadRegister(handle, TPS25730_REG_RX_SOURCE_CAPS, buffer, sizeof(buffer))) {
        return false;
    }

    // Parse header (byte 0)
    caps->num_valid_pdos = buffer[0] & 0x07;
    
    if (caps->num_valid_pdos > TPS25730_MAX_PDOS) {
        caps->num_valid_pdos = TPS25730_MAX_PDOS;
    }

    // Parse PDOs (4 bytes each, little endian)
    for (uint8_t i = 0; i < caps->num_valid_pdos; i++) {
        uint8_t offset = 1 + (i * 4);
        caps->pdos[i] = (uint32_t)buffer[offset] |
                       ((uint32_t)buffer[offset + 1] << 8) |
                       ((uint32_t)buffer[offset + 2] << 16) |
                       ((uint32_t)buffer[offset + 3] << 24);
    }

    return true;
}

/**
 * @brief Read received sink capabilities from port partner
 * @param handle: Pointer to driver handle
 * @param caps: Pointer to store sink capabilities
 * @return true if successful
 */
bool TPS25730_ReadRxSinkCaps(TPS25730_Handle *handle, TPS25730_SinkCaps *caps)
{
    uint8_t buffer[29];
    
    if (handle == NULL || caps == NULL) {
        return false;
    }

    if (!TPS25730_ReadRegister(handle, TPS25730_REG_RX_SINK_CAPS, buffer, sizeof(buffer))) {
        return false;
    }

    // Parse header (byte 0)
    caps->num_valid_pdos = buffer[0] & 0x07;
    
    if (caps->num_valid_pdos > TPS25730_MAX_PDOS) {
        caps->num_valid_pdos = TPS25730_MAX_PDOS;
    }

    // Parse PDOs (4 bytes each, little endian)
    for (uint8_t i = 0; i < caps->num_valid_pdos; i++) {
        uint8_t offset = 1 + (i * 4);
        caps->pdos[i] = (uint32_t)buffer[offset] |
                       ((uint32_t)buffer[offset + 1] << 8) |
                       ((uint32_t)buffer[offset + 2] << 16) |
                       ((uint32_t)buffer[offset + 3] << 24);
    }

    return true;
}

/**
 * @brief Read transmit sink capabilities (what we advertise)
 * @param handle: Pointer to driver handle
 * @param caps: Pointer to store sink capabilities
 * @return true if successful
 */
bool TPS25730_ReadTxSinkCaps(TPS25730_Handle *handle, TPS25730_SinkCaps *caps)
{
    uint8_t buffer[29];
    
    if (handle == NULL || caps == NULL) {
        return false;
    }

    if (!TPS25730_ReadRegister(handle, TPS25730_REG_TX_SINK_CAPS, buffer, sizeof(buffer))) {
        return false;
    }

    // Parse header (byte 0)
    caps->num_valid_pdos = buffer[0] & 0x07;
    
    if (caps->num_valid_pdos > TPS25730_MAX_PDOS) {
        caps->num_valid_pdos = TPS25730_MAX_PDOS;
    }

    // Parse PDOs (4 bytes each, little endian)
    for (uint8_t i = 0; i < caps->num_valid_pdos; i++) {
        uint8_t offset = 1 + (i * 4);
        caps->pdos[i] = (uint32_t)buffer[offset] |
                       ((uint32_t)buffer[offset + 1] << 8) |
                       ((uint32_t)buffer[offset + 2] << 16) |
                       ((uint32_t)buffer[offset + 3] << 24);
    }

    return true;
}
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

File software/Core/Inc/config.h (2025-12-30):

/**
 ******************************************************************************
 * @file    config.h
 * @brief   Centralized configuration for Ember hotplate
 * @date    December 16, 2025
 ******************************************************************************
 */

#ifndef CONFIG_H
#define CONFIG_H

#ifdef __cplusplus
extern "C" {
#endif

/* ============================================================================
 * System Configuration
 * ============================================================================ */
#define SYSTEM_CLOCK_HZ         64000000    // 64 MHz system clock

/* ============================================================================
 * Heater PWM Configuration (TIM2 CH1)
 * ============================================================================ */
#define HEATER_TIM_CLOCK_HZ     64000000    // Timer clock frequency
#define HEATER_PWM_FREQ_HZ      10          // PWM frequency (10 Hz for SSR/MOSFET)
#define HEATER_PWM_RESOLUTION   1000        // 0-1000 = 0.0% to 100.0% duty cycle

// Calculated timer values (do not modify)
#define HEATER_TIM_PRESCALER    ((HEATER_TIM_CLOCK_HZ / (HEATER_PWM_FREQ_HZ * HEATER_PWM_RESOLUTION)) - 1)
#define HEATER_TIM_PERIOD       (HEATER_PWM_RESOLUTION - 1)

/* ============================================================================
 * Speaker PWM Configuration (TIM1 CH1)
 * ============================================================================ */
#define SPEAKER_TIM_CLOCK_HZ    64000000    // Timer clock frequency

/* ============================================================================
 * Encoder Configuration (LPTIM1)
 * ============================================================================ */
#define ENCODER_COUNTS_PER_DETENT   2       // Encoder counts per click/detent

/* ============================================================================
 * Button Configuration
 * ============================================================================ */
#define BUTTON_DEBOUNCE_MS      30          // Button debounce time (ms)
#define BUTTON_LONG_PRESS_MS    500         // Long press threshold (ms)

/* ============================================================================
 * I2C Device Addresses
 * ============================================================================ */
#define TPS25730_I2C_ADDRESS    0x20        // USB-PD controller
#define TMP116_I2C_ADDR         0x48        // Temperature sensor (ADD0 = GND)
#define NFC_I2C_ADDRESS         0x55        // NT3H2111 NFC tag (7-bit address, byte=0x08)
#define OLED_I2C_ADDRESS        0xC3        // OLED display (7-bit address, byte=0xC3)

/* ============================================================================
 * NFC Configuration
 * ============================================================================ */
#define NFC_I2C_TIMEOUT_MS      100         // I2C timeout for NFC operations
#define NFC_POLL_INTERVAL_MS    100         // NFC polling interval (ms)
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

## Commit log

2025-11-17 peripherals and pinout
    [ember.kicad_sch]
2025-11-17 finished schematic and started PCB
    [BOM.csv, ember.kicad_pcb, ember.kicad_sch]
2025-11-18 finish schematic
    [ember.kicad_pcb, ember.kicad_sch]
2025-11-18 start routing
    [ember.kicad_pcb, ember.kicad_sch]
2025-11-20 udpate routing
    [ember.kicad_pcb, ember.kicad_sch]
2025-11-21 finished PCB
    [ember.kicad_pcb]
2025-11-21 changed buck
    [ember.kicad_pcb, ember.kicad_sch]
2025-11-21 different buck and heatbed
    [ember.kicad_pcb, heatbed.kicad_pcb, heatbed.kicad_sch]
2025-11-24 udpate pcb with fixes
    [ember.kicad_pcb, ember.kicad_sch]
2025-11-25 finish board and prod/case files
    [BOM.csv, Bottom Case.step, Ember.0001.iam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]
2025-11-25 add heatbed image
    [designators.csv, heatbed.kicad_pcb, heatbed.kicad_sch]
2025-11-25 update bom and case
    [BOM.csv, Bottom Case.step, Top Case.step]
2025-11-29 fixed via sizing
    [bom.csv, designators.csv, ember.kicad_pcb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]
2025-11-29 add in updated case
    [Bottom Case.step, Ember_NO_PCB.step, Top Case.step]
2025-12-05 update heatbed
    [heatbed.kicad_pcb, positions.csv]
2025-12-06 Correct heatbed dimensions in README
    Updated heatbed size in README from 400mm x 400mm and 200mm x 200mm to 120mm x 120mm.
2025-12-16 added speaker stuff and usb c pd driver
    [ember.kicad_sch]
2025-12-16 nfc stuff
    [ember.kicad_pcb, ember.kicad_sch]
2025-12-17 add in knoib and fix nfc
    [main.c, nfc.c, nt3h.c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]
2025-12-17 added in musicxml to custom speaker driver lol
2025-12-30 update code and flx haeter
    [ember.kicad_sch]

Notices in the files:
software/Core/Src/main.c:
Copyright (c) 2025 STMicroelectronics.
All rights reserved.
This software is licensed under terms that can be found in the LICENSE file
